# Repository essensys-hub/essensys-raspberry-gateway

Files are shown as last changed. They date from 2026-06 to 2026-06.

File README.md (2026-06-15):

# Essensys Gateway - CM5 Edition

Welcome to the hardware design repository for the **Essensys Gateway**, a high-performance home automation hub powered by the Raspberry Pi Compute Module 5 (CM5).

## Overview

The Essensys Gateway is designed as a modular, industrial-grade solution for controlling and monitoring the Essensys home automation ecosystem. It features a unique **3-board modular stack** architecture, separating core processing, high-speed storage/media, and connectivity into distinct physical layers.

**Industrial Ready**: Designed for DIN Rail mounting with a dedicated enclosure and industrial power input.

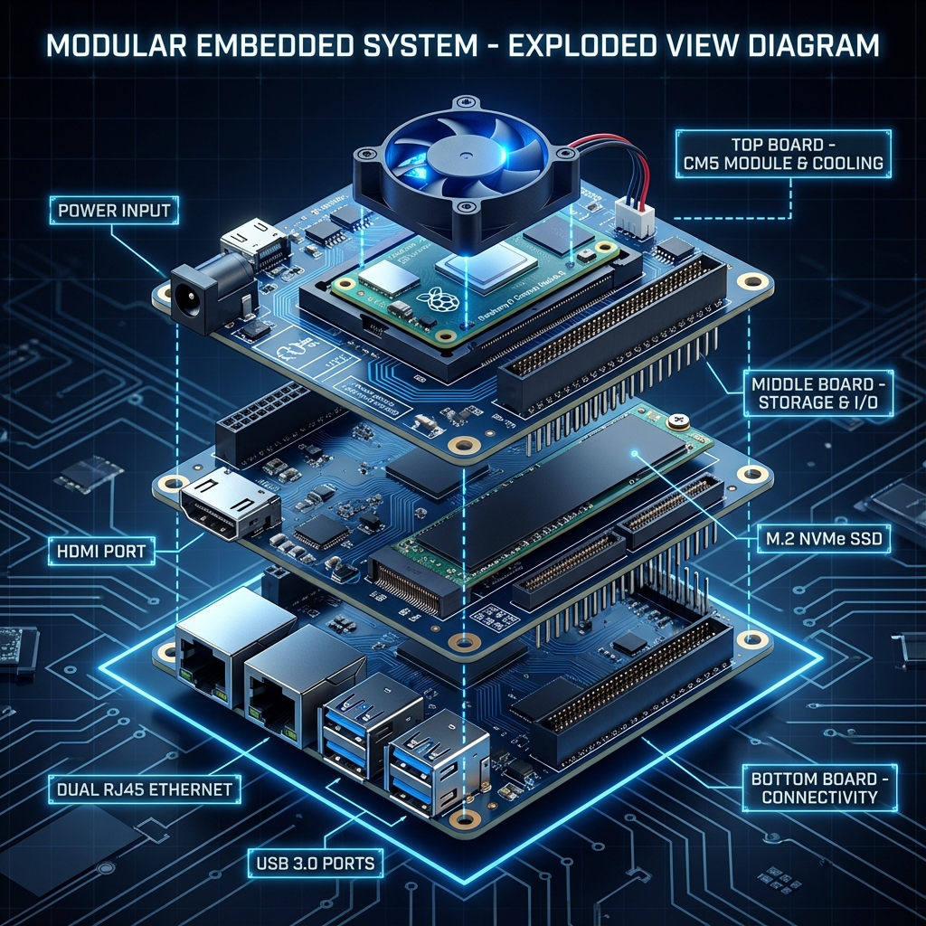
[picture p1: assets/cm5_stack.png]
Essensys CM5 Modular Stack Concept

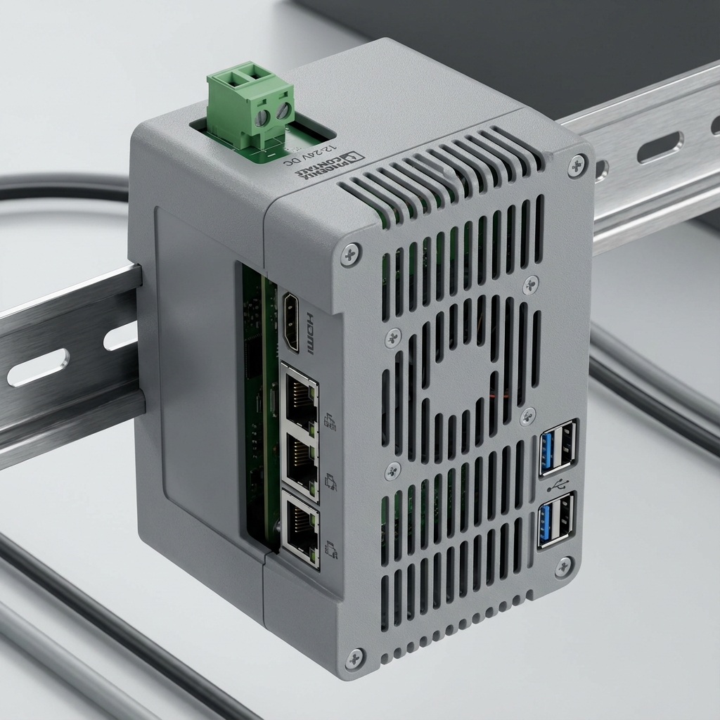
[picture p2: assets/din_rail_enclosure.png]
DIN Rail Enclosure Visualization


## Architecture

The system is built as a "sandwich" of three stacked PCBs (100mm x 100mm), interconnected by high-density Mezzanine connectors:

### 1. Top Board: Core & Processing
The brain of the operation.
- **Compute Module**: Raspberry Pi CM5 (Quad-core ARM Cortex-A76).
- **Cooling**: Dedicated active cooling fan with PWM control.
- **Power**: 2-Pin Terminal Block (Bornier) for 12V-24V DC Input.

### 2. Middle Board: Storage & Media
Dedicated layer for high-speed extensions.
- **Storage**: M.2 M-Key slot for NVMe SSDs (PCIe Gen 2 x1).
- **Video**: Full-size HDMI output for local display or debugging.

### 3. Bottom Board: Connectivity
High-density IO for network integration.
- **Ethernet**: 
  - 1x Gigabit Ethernet (Native CM5).
  - 1x Gigabit Ethernet (via USB 3.0 Bridge).
- **USB**: 3x USB 3.0 Type-A ports for peripherals (Z-Wave/Zigbee sticks, etc.).

## Specifications

| Feature | Specification |
| :--- | :--- |
| **Processor** | Raspberry Pi Compute Module 5 |
| **RAM** | Up to 8GB LPDDR4X (depending on CM5 variant) |
| **Storage** | M.2 NVMe SSD (2230/2242/2280 supported via Mid Board) |
| **Network** | Dual Gigabit Ethernet (1x Native, 1x RTL8153) |
| **USB** | 3x USB 3.0 (via VL817 Hub) |
| **Video** | 1x HDMI 2.0 (4Kp60 supported) |
| **Power** | 12V-24V DC Industrial Input (Terminal Block) |
| **Dimensions** | 100mm x 100mm x 45mm (DIN Rail Mountable) |

## Repository Structure

- `src/cm5/`: KiCad Design Files
  - `CM5_Stack_Top/`: Top board design (CM5 + Fan).
  - `CM5_Stack_Mid/`: Middle board design (M.2 + HDMI).
  - `CM5_Stack_Bot/`: Bottom board design (Dual Eth + USB Hub).
- `docs/`: **Documentation MkDocs** (miroir structure [essensys-raspberry-install](https://github.com/essensys-hub/essensys-raspberry-install), adaptée Gateway CM5)
- `nix/`: Configuration NixOS (branche `nixos`)
- `scripts/`: Tests WAN HTTPS, utilitaires déploiement

## Documentation

Site en ligne : [essensys-hub.github.io/essensys-raspberry-gateway](https://essensys-hub.github.io/essensys-raspberry-gateway/)

```bash
pip install mkdocs-material mkdocs-minify-plugin mkdocs-git-revision-date-localized-plugin
mkdocs serve   # http://127.0.0.1:8000
```

## Manufacturing & Assembly

This project is designed for manufacturing services like [PCBWay](https://www.pcbway.com/).
- **PCB Stackup**: 4-Layer controlled impedance (JLC2313 or similar).
- **Assembly**: SMT assembly required for high-density connectors and BGA/QFN components (VL817, RTL8153).
- **Connectors**: Uses high-speed board-to-board mezzanine connectors for robust signal integrity of PCIe and USB 3.0 signals between layers.

---
*Designed for the Essensys Smart Home Project.*

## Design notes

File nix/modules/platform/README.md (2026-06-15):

# CM5 / Pi5 NixOS platform notes

This module enables a **headless** Raspberry Pi CM5 profile using `pkgs.linuxPackages_rpi4`
(nixpkgs community path for Pi 5-class hardware).

## Prerequisites (manual, before first NixOS install)

1. Flash or install base firmware on CM5 eMMC.
2. Enable **PCIe / NVMe** in CM5 EEPROM or firmware config per Raspberry Pi documentation.
3. Verify `lsblk` shows `nvme0n1` before relying on `services.essensys.nvme`.
4. Note **MAC addresses** for eth0 (native) and eth1 (USB RTL8153 on Essensys IO board):
   `ip link show`

## Kernel alternatives

- **Default here**: `linuxPackages_rpi4` on nixos-24.11
- **Alternative**: pin `nixos-raspberrypi` flake input for vendor kernel (see `docs/nixos-install-cm5.md`)

## Initrd

NVMe modules are added when `services.essensys.nvme.enable = true`.

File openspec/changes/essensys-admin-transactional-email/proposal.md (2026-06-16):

## Why

Admins create users and assign gateways/armoires via the support-site admin (`UserManager`), but **no transactional email** is sent (welcome credentials, allocation summary, password reset). Operators must manually communicate access details. SMTP is configured for **newsletter only** (`internal/admin/newsletter.go`), causing support friction and user confusion when accounts are created without notification.

## What Changes

- **Transactional email engine** in `essensys-user-portal-backend`: reusable mailer built on existing `SMTP_*` / gomail, separate from newsletter drafts.
- **Email templates** stored in PostgreSQL, editable in admin UI: types `user_welcome`, `device_allocation`, `password_reset`, `role_updated` (extensible).
- **Template variables** (`{{first_name}}`, `{{email}}`, `{{portal_url}}`, `{{gateway_name}}`, `{{gateway_ip}}`, `{{armoire_label}}`, `{{temporary_password}}`, etc.).
- **Auto-send hooks**: optional send on `CreateUser`, `UpdateUserLinks` when template `auto_send=true`.
- **Resend button** per user row: « Renvoyer email » (welcome or allocation template).
- **Admin section** new tab « Modèles email » in `essensys-support-site/site/src/pages/Admin.jsx`.
- **Audit log** entries for every send / resend / failure.
- **SMTP health**: admin-visible status + test send endpoint.

## Capabilities

### New Capabilities

- `transactional-email-engine`: send, render templates, SMTP errors, audit.
- `email-templates-admin`: CRUD templates, preview, enable/disable auto-send per type.
- `user-lifecycle-notifications`: hooks on user create, link update, password reset (phase 2).
- `admin-ui-email-actions`: resend button, templates editor, test email.

### Modified Capabilities

- `admin-module-migration`: extend admin routes with `/api/admin/email-templates/*`, `/api/admin/email/health`, and `/api/admin/users/{id}/resend-email`.

## Impact

- **Modified repos**: `essensys-user-portal-backend` (primary), `essensys-support-site/site` (admin UI), docs.
- **Ansible**: no new secrets — reuse `vault_smtp_*` in `cloud-backend.env.j2`.
- **DB**: migration `006_email_templates.sql` + `email_send_log` table.
- **Non-goals (MVP)**: SMS, multi-language templates, HTML WYSIWYG builder, user-facing notification preferences.

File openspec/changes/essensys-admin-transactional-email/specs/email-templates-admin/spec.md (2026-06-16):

## ADDED Requirements

### Requirement: Admin CRUD for email templates
The backend SHALL expose routes under `/api/admin/email-templates` protected by `AdminAuth` and restricted to `admin_global` for write operations.

| Method | Path | Action |
|---|---|---|
| GET | `/api/admin/email-templates` | List all templates |
| GET | `/api/admin/email-templates/{slug}` | Get one template |
| PUT | `/api/admin/email-templates/{slug}` | Create or update template |
| POST | `/api/admin/email-templates/{slug}/preview` | Render preview with sample or provided data |
| POST | `/api/admin/email-templates/test` | Send test email to requesting admin |

#### Scenario: List templates
- **WHEN** `admin_global` requests `GET /api/admin/email-templates`
- **THEN** the response includes all slugs with subject, `enabled`, and `auto_send` flags

#### Scenario: Update template body
- **WHEN** `admin_global` sends `PUT /api/admin/email-templates/user_welcome` with new subject and body
- **THEN** the template is persisted and returned with updated `updated_at`

### Requirement: Template schema
Each template row SHALL include: `slug` (unique), `name`, `subject`, `body_html`, `body_text`, `enabled` (bool), `auto_send` (bool), `created_at`, `updated_at`.

#### Scenario: Disable template
- **WHEN** `enabled` is set to `false`
- **THEN** auto-send hooks and resend using that slug return HTTP 400 or skip with clear message

### Requirement: Default templates seeded on migration
Migration `006_email_templates.sql` SHALL seed disabled default templates for slugs: `user_welcome`, `device_allocation`, `password_reset`, `role_updated`.

#### Scenario: Fresh database migration
- **WHEN** migration runs on an empty database
- **THEN** four template rows exist with French placeholder content and `enabled=false`, `auto_send=false`

### Requirement: Documented template variables
Admin API documentation SHALL list allowed placeholders: `first_name`, `last_name`, `email`, `role`, `portal_url`, `temporary_password`, `gateway_name`, `gateway_ip`, `armoire_label`, `armoire_ip`, `support_email`.

#### Scenario: Preview with sample data
- **WHEN** admin posts to preview endpoint without custom payload
- **THEN** the response shows rendered subject and body using built-in sample values

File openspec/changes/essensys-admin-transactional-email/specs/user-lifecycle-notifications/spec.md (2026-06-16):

## ADDED Requirements

### Requirement: Optional auto-send on user creation
When `POST /api/admin/users` succeeds and template `user_welcome` has `enabled=true` and `auto_send=true`, the backend SHALL send the welcome email using the plaintext password from the request body.

#### Scenario: Welcome auto-send enabled
- **WHEN** admin creates a user and `user_welcome` has `auto_send=true`
- **THEN** the user receives a welcome email and audit logs `EMAIL_SENT` with slug `user_welcome`

#### Scenario: Welcome auto-send disabled
- **WHEN** `user_welcome.auto_send` is `false`
- **THEN** the user is created without email; admin may trigger resend later

#### Scenario: Create succeeds even if email fails
- **WHEN** user creation succeeds but SMTP send fails
- **THEN** HTTP 201 or 200 is still returned for user creation, email failure is logged, and response may include `email_sent: false`

### Requirement: Optional auto-send on device allocation
When `PUT /api/admin/users/{id}/links` updates `linked_gateway_id` or `linked_armoire_id` and template `device_allocation` has `enabled=true` and `auto_send=true`, the backend SHALL send an allocation summary email.

#### Scenario: Link gateway and armoire
- **WHEN** admin saves links for a user with gateway hostname and armoire machine resolved
- **THEN** the email includes gateway name/IP and armoire label/IP in rendered template variables

#### Scenario: Allocation template disabled
- **WHEN** `device_allocation.enabled` is `false`
- **THEN** link update completes without sending email

### Requirement: Resend email for existing user
The backend SHALL expose `POST /api/admin/users/{id}/resend-email` accepting `{ "template_slug": string, "password": string optional }`.

#### Scenario: Resend welcome with password
- **WHEN** admin resends `user_welcome` with `password` in body
- **THEN** email is sent with `{{temporary_password}}` substituted and attempt is logged

#### Scenario: Resend welcome without password
- **WHEN** admin resends `user_welcome` without password and template contains `{{temporary_password}}`
- **THEN** placeholder is replaced with a French fallback such as « contactez votre administrateur » or API returns HTTP 400 requiring password

#### Scenario: Resend allocation template
- **WHEN** admin resends `device_allocation` for a user with linked devices
- **THEN** current gateway and armoire data are resolved and included in the email

### Requirement: Password reset email deferred to phase 2
`POST /api/auth/forgot-password` is out of MVP scope; template `password_reset` SHALL be seeded but not wired until phase 2.

#### Scenario: Forgot password not implemented in MVP
- **WHEN** client calls `POST /api/auth/forgot-password` before phase 2
- **THEN** endpoint may return HTTP 501 or remain unregistered; documented in tasks phase 2

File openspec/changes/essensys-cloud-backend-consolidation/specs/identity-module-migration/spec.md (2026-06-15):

## ADDED Requirements

### Requirement: OAuth and email auth routes preserved
The consolidated backend SHALL expose the same auth routes as `essensys-support-site/backend`: register, login, logout, Google OAuth, Apple OAuth, and admin login (deprecated).

#### Scenario: Email login returns JWT
- **WHEN** a user posts valid credentials to `POST /api/auth/login`
- **THEN** the response includes a JWT and user object with the same shape as the support-site backend

#### Scenario: Google OAuth redirect unchanged
- **WHEN** a browser requests `GET /api/auth/google/login`
- **THEN** the user is redirected to Google OAuth with the same callback URL path `/api/auth/google/callback`

### Requirement: JWT emit and validate in same binary
The consolidated backend SHALL sign JWTs in the identity module and validate them in portal/admin middleware using the same `JWT_SECRET`.

#### Scenario: Portal accepts JWT from consolidated login
- **WHEN** a user logs in via consolidated backend and calls `POST /api/portal/inject` with the returned JWT
- **THEN** the request is authenticated without calling an external auth service

### Requirement: Profile routes preserved
Routes `GET/PUT/DELETE /api/profile`, `GET /api/profile/export`, `PUT /api/profile/links`, and `GET /api/devices/nearby` SHALL remain available with identical paths and authorization rules.

#### Scenario: Profile read after OAuth login
- **WHEN** an authenticated user requests `GET /api/profile`
- **THEN** the response includes email, role, and linked device fields from PostgreSQL `users`

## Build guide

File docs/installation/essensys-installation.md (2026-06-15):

# Étape 4 : Installation d'Essensys

!!! info "Gateway CM5 (ce dépôt)"
    Sur **Gateway CM5**, utilisez **Ansible** et non `install.sh` :
    ```bash
    cd essensys-ansible
    ansible-playbook install.gateway.yml -i inventory.gateway
    ```
    Voir [Gateway CM5 (dual-NIC)](gateway-cm5.md). La section ci-dessous décrit encore le parcours **Raspberry Pi 4** historique (`install.raspberrypi.yml` / `install.sh`).

Cette section explique comment installer Essensys (backend et frontend) sur le Raspberry Pi en fonction de l'utilisateur que vous avez choisi lors de l'installation de l'OS.

## Prérequis

- [ ] Raspberry Pi OS installé et démarré.
- [ ] Connexion SSH établie.
- [ ] Accès Internet fonctionnel sur le Raspberry Pi.

---

## Méthode d'installation

Choisissez la méthode correspondant à votre nom d'utilisateur configuré à l'étape précédente.

=== "Utilisateur `essensys` (Recommandé)"

    Si vous avez respecté le nom d'utilisateur `essensys`, vous pouvez utiliser la commande rapide :

    1. **Connectez-vous en SSH** :
       ```bash
       ssh essensys@<ip-du-pi>
       ```

    2. **Lancez l'installation automatique** :
       ```bash
       sudo curl -sL https://raw.githubusercontent.com/essensys-hub/essensys-raspberry-install/refs/heads/V.1.1.0/install.sh | sudo bash
       ```

       example: 
       ```
essensys@essensys-server:~ $ sudo curl -sL https://raw.githubusercontent.com/essensys-hub/essensys-raspberry-install/refs/heads/V.1.1.0/install.sh | sudo bash
[INFO] Verification des prerequis (git, ansible)...
Hit:1 http://deb.debian.org/debian trixie InRelease
Get:2 http://deb.debian.org/debian trixie-updates InRelease [47.3 kB]                                        
Hit:3 http://archive.raspberrypi.com/debian trixie InRelease                                                 
Get:4 http://deb.debian.org/debian-security trixie-security InRelease [43.4 kB]                              
Hit:5 https://deb.nodesource.com/node_20.x nodistro InRelease                         
Fetched 90.7 kB in 0s (211 kB/s)
Reading package lists... Done
[INFO] Git deja installe
[INFO] Execution via curl | bash detectee, bootstrap du depot...
[INFO] Depot essensys-raspberry-install deja present, mise a jour...
Already up to date.
----------------------------------------
DOMAIN_FILE: /home/essensys/domain.txt
----------------------------------------
[INFO] domain.txt detecte. Saisissez le domaine WAN a utiliser.
[INFO] ref: https://essensys-hub.github.io/essensys-raspberry-install/installation/wan/
Domaine WAN (ex: mon.monwan.io):  essensys.rhinosys.io 
[INFO] Domaine enregistre dans /home/essensys/domain.txt
```
Il faut mettre le nom du DNS relier à votre adresse de votre installation WAN router.

```
[WARN] resize2fs_once introuvable, etape ignoree
[INFO] Ansible deja installe
[INFO] Depot deja present, mise a jour...
remote: Enumerating objects: 56, done.
remote: Counting objects: 100% (56/56), done.
remote: Compressing objects: 100% (39/39), done.
remote: Total 51 (delta 7), reused 51 (delta 7), pack-reused 0 (from 0)
Unpacking objects: 100% (51/51), 2.68 MiB | 13.51 MiB/s, done.
From https://github.com/essensys-hub/essensys-ansible
   95a3729..7ed78a0  V.1.0.0    -> origin/V.1.0.0
 + ed7ac00...104dde6 gh-pages   -> origin/gh-pages  (forced update)
Already on 'V.1.0.0'
Your branch is behind 'origin/V.1.0.0' by 1 commit, and can be fast-forwarded.
  (use "git pull" to update your local branch)
Updating 95a3729..7ed78a0
Fast-forward
 roles/raspberry_push_status/files/push_status.py | 4 ++--
 1 file changed, 2 insertions(+), 2 deletions(-)
[INFO] Lancement du playbook d'installation Raspberry Pi...

PLAY [Installation Essensys Raspberry Pi] *****************************************************************************************************************************************

TASK [Gathering Facts] ************************************************************************************************************************************************************
[WARNING]: Host 'localhost' is using the discovered Python interpreter at '/usr/bin/python3.13', but future installation of another Python interpreter could cause a different interpreter to be discovered. See https://docs.ansible.com/ansible-core/2.19/reference_appendices/interpreter_discovery.html for more information.
ok: [localhost]

TASK [raspberry_common : Mettre a jour le cache APT] ******************************************************************************************************************************
ok: [localhost]

TASK [raspberry_common : Installer les dependances systeme] ***********************************************************************************************************************
ok: [localhost]

TASK [raspberry_common : Definir les variables d'architecture] ********************************************************************************************************************
ok: [localhost]

TASK [raspberry_common : Verifier la presence de Go] ******************************************************************************************************************************
ok: [localhost]

TASK [raspberry_common : Telecharger Go] ******************************************************************************************************************************************
skipping: [localhost]

TASK [raspberry_common : Installer Go] ********************************************************************************************************************************************
skipping: [localhost]

TASK [raspberry_common : Ajouter Go au PATH systeme] ******************************************************************************************************************************
ok: [localhost]

TASK [raspberry_common : Telecharger le script Node.js] ***************************************************************************************************************************
ok: [localhost]

TASK [raspberry_common : Executer le script Node.js] ******************************************************************************************************************************
ok: [localhost]

TASK [raspberry_common : Installer Node.js] ***************************************************************************************************************************************
ok: [localhost]

TASK [raspberry_common : Creer l'utilisateur de service] **************************************************************************************************************************
ok: [localhost]

TASK [raspberry_common : Creer les repertoires d'installation] ********************************************************************************************************************
ok: [localhost] => (item=/opt/essensys)
changed: [localhost] => (item=/opt/essensys/backend)
changed: [localhost] => (item=/opt/essensys/frontend)
ok: [localhost] => (item=/opt/essensys/logs)

TASK [raspberry_common : Creer le repertoire de logs backend] *********************************************************************************************************************
ok: [localhost] => (item=/var/logs/Essensys)
ok: [localhost] => (item=/var/logs/Essensys/backend)

TASK [raspberry_common : S'assurer que Redis est actif] ***************************************************************************************************************************
ok: [localhost]

TASK [raspberry_backend : Definir variables backend] ******************************************************************************************************************************
ok: [localhost]

TASK [raspberry_backend : Cloner ou mettre a jour le backend] *********************************************************************************************************************
changed: [localhost]

TASK [raspberry_backend : Arreter le service backend avant mise a jour] ***********************************************************************************************************
ok: [localhost]

TASK [raspberry_backend : Copier le backend vers le repertoire d'installation] ****************************************************************************************************
changed: [localhost]

TASK [raspberry_backend : Synchroniser les dependances Go] ************************************************************************************************************************
changed: [localhost]

TASK [raspberry_backend : Telecharger les dependances Go si necessaire] ***********************************************************************************************************
skipping: [localhost]

TASK [raspberry_backend : Reexecuter go mod tidy apres download] ******************************************************************************************************************
skipping: [localhost]

TASK [raspberry_backend : Compiler le backend] ************************************************************************************************************************************
changed: [localhost]

TASK [raspberry_backend : Creer le fichier config.yaml si absent] *****************************************************************************************************************
ok: [localhost]

TASK [raspberry_backend : Forcer le port 7070 dans config.yaml] *******************************************************************************************************************
changed: [localhost]

TASK [raspberry_backend : Installer le service systemd du backend] ****************************************************************************************************************
ok: [localhost]

TASK [raspberry_backend : Recharger systemd] **************************************************************************************************************************************
ok: [localhost]

TASK [raspberry_backend : Definir les permissions du backend] *********************************************************************************************************************
changed: [localhost]

TASK [raspberry_backend : Demarrer le service backend] ****************************************************************************************************************************
changed: [localhost]

TASK [raspberry_backend : S'assurer que Redis est actif] **************************************************************************************************************************
ok: [localhost]

TASK [raspberry_frontend : Definir variables frontend] ****************************************************************************************************************************
ok: [localhost]

TASK [raspberry_frontend : Cloner ou mettre a jour le frontend] *******************************************************************************************************************
ok: [localhost]

TASK [raspberry_frontend : Copier le frontend vers le repertoire d'installation] **************************************************************************************************
changed: [localhost]

TASK [raspberry_frontend : Installer les dependances npm] *************************************************************************************************************************
changed: [localhost]

TASK [raspberry_frontend : Builder le frontend] ***********************************************************************************************************************************
changed: [localhost]

TASK [raspberry_frontend : Verifier la presence du build] *************************************************************************************************************************
ok: [localhost]

TASK [raspberry_frontend : Echouer si le build est absent] ************************************************************************************************************************
skipping: [localhost]

TASK [raspberry_frontend : Definir les permissions du frontend] *******************************************************************************************************************
ok: [localhost]

TASK [raspberry_nginx : Copier le format de log nginx] ****************************************************************************************************************************
ok: [localhost]

TASK [raspberry_nginx : Deployer la configuration nginx principale] ***************************************************************************************************************
ok: [localhost]

TASK [raspberry_nginx : Activer le site nginx] ************************************************************************************************************************************
ok: [localhost]

TASK [raspberry_nginx : Desactiver la configuration nginx par defaut] *************************************************************************************************************
ok: [localhost]

TASK [raspberry_nginx : Deployer la configuration nginx frontend interne] *********************************************************************************************************
ok: [localhost]

TASK [raspberry_nginx : Activer le site nginx frontend interne] *******************************************************************************************************************
ok: [localhost]

TASK [raspberry_nginx : Creer les fichiers de logs nginx] *************************************************************************************************************************
changed: [localhost] => (item=/var/log/nginx/essensys-api-detailed.log)
changed: [localhost] => (item=/var/log/nginx/essensys-api-trace.log)
changed: [localhost] => (item=/var/log/nginx/essensys-api-error.log)
changed: [localhost] => (item=/var/log/nginx/essensys-access.log)
changed: [localhost] => (item=/var/log/nginx/essensys-error.log)
changed: [localhost] => (item=/var/log/nginx/frontend-internal-error.log)

TASK [raspberry_nginx : Tester la configuration nginx] ****************************************************************************************************************************
ok: [localhost]

TASK [raspberry_nginx : Recharger nginx] ******************************************************************************************************************************************
changed: [localhost]

TASK [raspberry_traefik : Definir les variables Traefik] **************************************************************************************************************************
ok: [localhost]

TASK [raspberry_traefik : Verifier le binaire Traefik] ****************************************************************************************************************************
ok: [localhost]

TASK [raspberry_traefik : Lire le domaine WAN] ************************************************************************************************************************************
ok: [localhost]

TASK [raspberry_traefik : Calculer le domaine WAN] ********************************************************************************************************************************
ok: [localhost]

TASK [raspberry_traefik : Telecharger Traefik] ************************************************************************************************************************************
skipping: [localhost]

TASK [raspberry_traefik : Extraire Traefik] ***************************************************************************************************************************************
skipping: [localhost]

TASK [raspberry_traefik : Installer le binaire Traefik] ***************************************************************************************************************************
skipping: [localhost]

TASK [raspberry_traefik : Creer les repertoires Traefik] **************************************************************************************************************************
ok: [localhost] => (item=/etc/traefik)
ok: [localhost] => (item=/etc/traefik/dynamic)
ok: [localhost] => (item=/var/log/traefik)
ok: [localhost] => (item=/var/lib/traefik)

TASK [raspberry_traefik : Deployer la configuration Traefik] **********************************************************************************************************************
ok: [localhost]

TASK [raspberry_traefik : Deployer la configuration dynamique locale] *************************************************************************************************************
ok: [localhost]

TASK [raspberry_traefik : Deployer la configuration dynamique WAN] ****************************************************************************************************************
ok: [localhost]

TASK [raspberry_traefik : Creer acme.json] ****************************************************************************************************************************************
changed: [localhost]

TASK [raspberry_traefik : Creer users.htpasswd] ***********************************************************************************************************************************
changed: [localhost]

TASK [raspberry_traefik : Installer le service de blocage Traefik] ****************************************************************************************************************
ok: [localhost]

TASK [raspberry_traefik : Installer generate-htpasswd.sh] *************************************************************************************************************************
ok: [localhost]

TASK [raspberry_traefik : Installer le service systemd Traefik block] *************************************************************************************************************
ok: [localhost]

TASK [raspberry_traefik : Installer le service systemd Traefik] *******************************************************************************************************************
ok: [localhost]

TASK [raspberry_traefik : Recharger systemd] **************************************************************************************************************************************
ok: [localhost]

TASK [raspberry_traefik : Activer et demarrer Traefik] ****************************************************************************************************************************
changed: [localhost]

TASK [raspberry_traefik : Activer et demarrer le service de blocage] **************************************************************************************************************
changed: [localhost]

TASK [raspberry_adguard : Definir l'architecture AdGuard] *************************************************************************************************************************
ok: [localhost]

TASK [raspberry_adguard : Verifier resolved.conf] *********************************************************************************************************************************
ok: [localhost]

TASK [raspberry_adguard : Desactiver DNSStubListener pour systemd-resolved] *******************************************************************************************************
skipping: [localhost]

TASK [raspberry_adguard : Verifier resolv.conf source] ****************************************************************************************************************************
ok: [localhost]

TASK [raspberry_adguard : Verifier resolv.conf] ***********************************************************************************************************************************
skipping: [localhost]

TASK [raspberry_adguard : Installer AdGuard Home] *********************************************************************************************************************************
skipping: [localhost]

TASK [raspberry_adguard : Deployer la configuration AdGuard Home] *****************************************************************************************************************
ok: [localhost]

TASK [raspberry_adguard : Installer le service AdGuard Home] **********************************************************************************************************************
ok: [localhost]

TASK [raspberry_adguard : Demarrer AdGuard Home] **********************************************************************************************************************************
changed: [localhost]

TASK [raspberry_adguard : Attendre l'API AdGuard] *********************************************************************************************************************************
ok: [localhost]

TASK [raspberry_adguard : Configurer le rewrite DNS pour mon.essensys.fr] *********************************************************************************************************
ok: [localhost]

TASK [raspberry_monitor : Copier le script de monitoring] *************************************************************************************************************************
ok: [localhost]

TASK [raspberry_monitor : Copier le setup du monitoring] **************************************************************************************************************************
ok: [localhost]

TASK [raspberry_monitor : Executer le setup du monitoring] ************************************************************************************************************************
changed: [localhost]

TASK [raspberry_logrotate : Installer la configuration logrotate] *****************************************************************************************************************
ok: [localhost]

TASK [raspberry_push_status : Copier le script de push status] ********************************************************************************************************************
changed: [localhost]

TASK [raspberry_push_status : Installer le service systemd de push status] ********************************************************************************************************
ok: [localhost]

TASK [raspberry_push_status : Installer le timer systemd de push status] **********************************************************************************************************
ok: [localhost]

TASK [raspberry_push_status : Recharger systemd] **********************************************************************************************************************************
ok: [localhost]

TASK [raspberry_push_status : Activer le timer push status] ***********************************************************************************************************************
ok: [localhost]

PLAY RECAP ************************************************************************************************************************************************************************
localhost                  : ok=76   changed=20   unreachable=0    failed=0    skipped=11   rescued=0    ignored=0   
[INFO] Configuration du mot de passe WAN (admin)...
Mot de passe: 
Note : saisissez le mot de passe utilise pour la connexion WAN.
[INFO] Generation du fichier htpasswd...
[WARN] Le fichier existe deja. Ajout de l'utilisateur...
[INFO] Fichier htpasswd cree avec succes: /etc/traefik/users.htpasswd
[INFO] Utilisateur: admin
[INFO] 
[INFO] Pour ajouter d'autres utilisateurs, executez a nouveau ce script
[INFO] Termine. Installation lancee via Ansible.
essensys@essensys-server:~ $ 

=== "Autre utilisateur (Personnalisé)"

    Si vous utilisez un nom d'utilisateur différent (ex: `pi`, `admin`), vous devez cloner le projet manuellement :

    1. **Connectez-vous en SSH** :
       ```bash
       ssh <votre-user>@<ip-du-pi>
       ```

    2. **Clonez le dépôt** :
       ```bash
       git clone https://github.com/essensys-hub/essensys-raspberry-install
       cd essensys-raspberry-install
       ```

    3. **Lancez l'installation avec votre utilisateur** :
       ```bash
       chmod +x install.sh
       sudo ./install.sh --user <votre-user>
       ```

---

## Options du script (Optionnel)

Le script `install.sh` accepte des arguments pour des configurations spécifiques :

| Option | Description |
| :--- | :--- |
| `--staging` | Active l'environnement de test (staging) pour Let's Encrypt. |
| `--user <username>` | Définit l'utilisateur cible (obligatoire si différent de `essensys`). |

## Architecture installée

```mermaid
graph TB
    Client[Client Essensys]
    Nginx[Nginx<br/>Port 80]
    Backend[Backend Go<br/>Port 7070]
    Frontend[Frontend React]
    
    Client -->|API/Web| Nginx
    Nginx -->|/api/*| Backend
    Nginx -->|/| Frontend
    
    style Nginx fill:#e8f5e9
    style Backend fill:#f3e5f5
```

---

!!! warning "L'adresse IP `192.168.1.151` utilisée dans cet exemple est fictive"
    Vous devez impérativement identifier l'adresse IP réelle de votre "essensys client" sur votre réseau local pour configurer les redirections de port correctement.

!!! success "Installation Terminée !"
    Félicitations ! Votre serveur Essensys est maintenant opérationnel.
    
    [:material-lan: **Configurer le réseau**](../connexion/configuration-reseau.md){ .md-button .md-button--primary }

## Dépannage

### Vérifier les services
```bash
sudo systemctl status essensys-backend
sudo systemctl status essensys-frontend
sudo systemctl status nginx
```

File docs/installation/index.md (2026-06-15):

# Introduction — Installation Gateway CM5

Cette section décrit le parcours d'installation de la **Gateway Essensys** (Compute Module 5, double RJ45).

[:material-play-circle: **Guide complet dual-NIC**](gateway-cm5.md){ .md-button .md-button--primary }

## Parcours recommandé

| Étape | Page | Description |
|---|---|---|
| 1 | [Préparation CM5](preparation-cm5.md) | Matériel, NVMe, firmware PCIe |
| 2 | [OS Debian](os-installation.md) ou [NixOS](nixos-cm5.md) | Système sur eMMC |
| 3 | [Domaine WAN](wan.md) | DuckDNS / NAT (optionnel) |
| 4 | [Déploiement Ansible](essensys-installation.md) | `install.gateway.yml` |
| 5 | [Accès](acces/index.md) | Local, WAN, [portail remote](../acces/portal-remote.md) |

## Deux systèmes d'exploitation

| OS | Playbook / outil | Quand |
|----|---|---|
| **Debian 13 + Docker** | `ansible-playbook install.gateway.yml` | Production actuelle |
| **NixOS** | `prepare.nixos-cm5.yml` puis `nixos-rebuild switch` | Variante déclarative (branche `nixos`) |

Les deux profils partagent le même modèle réseau : **eth0** = LAN/Internet, **eth1** = armoire `10.0.1.0/24`.

```bash
cd essensys-ansible
ansible-playbook install.gateway.yml -i inventory.gateway
```

## Inventaire

Variables clés dans `inventory.gateway` : `gateway_eth0_mac`, `gateway_eth1_mac`, `gateway_eth1_ip`, `gateway_armoire_hostname` (`mon.essensys.fr`), NVMe, cloud hub URL.

Voir [Gateway CM5 — section 6](gateway-cm5.md#6-deploiement) pour le détail.

## Raspberry Pi 4 (mono-interface)

Pour l'installation historique sur **Raspberry Pi 4** (un seul réseau), consultez
[essensys-raspberry-install](https://github.com/essensys-hub/essensys-raspberry-install/docs/installation/).

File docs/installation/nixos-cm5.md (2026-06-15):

# Préparation et installation NixOS — Gateway CM5

Guide pour la branche **`nixos`** de `essensys-raspberry-gateway` : profil **dual-NIC** déclaratif (eth0 LAN/HTTPS, eth1 armoire/DHCP/HTTP legacy).

!!! info "Deux OS pour la même Gateway"
    **Production actuelle** : Debian 13 + Docker via [Gateway CM5 (dual-NIC)](gateway-cm5.md).
    **NixOS** : même réseau et même NVMe, configuration via flake Nix.

---

## Partie A — Préparation Ansible

| Playbook | Rôle | Usage |
|---|---|---|
| `uninstall.cm5.yml` | `raspberry_cm5_uninstall` | Retire stack Debian/Ansible/Docker |
| `prepare.nixos-cm5.yml` | `raspberry_cm5_nixos` | Clone flake, installe Nix, prépare eMMC/NVMe |

```bash
cd essensys-ansible

ansible-playbook uninstall.cm5.yml -i inventory.gateway \
  -e confirm_cm5_uninstall=true

ansible-playbook prepare.nixos-cm5.yml -i inventory.gateway \
  -e confirm_cm5_nixos_prep=true
```

Après `prepare` :

- Flake : `/opt/essensys-nixos`
- Hardware généré : `nix/hosts/gateway-cm5/hardware-cm5.generated.nix`
- Script eMMC : `/usr/local/sbin/essensys-prepare-nixos-mmc.sh`

!!! warning "Repartition eMMC"
    Ne pas repartitionner l'eMMC depuis le système qui boot dessus. Utiliser un media recovery, puis `nixos-install --flake /opt/essensys-nixos#gateway-cm5`.

---

## Partie B — Installation NixOS (flake)

### Prérequis poste de build

- [Nix](https://nixos.org/download.html) avec flakes (`experimental-features = nix-command flakes`)
- Dépôt cloné, branche `nixos`
- `essensys-nginx` en sibling ou via flake input

### Configuration hôte

Éditer `nix/hosts/gateway-cm5/default.nix` :

| Option | Description |
|---|---|
| `gateway.eth0Mac` / `eth1Mac` | MAC réelles |
| `gateway.eth1Address` | IP statique armoire (ex. `10.0.1.1`) |
| `gateway.eth0Address` | IP LAN fixe si `bindStrict` ; `null` = DHCP |
| `nvme.device` | `/dev/disk/by-label/essensys-data` |

### Installation

```bash
# Sur la CM5
nixos-install --flake .#gateway-cm5 --no-root-password
reboot
```

Déploiement à distance :

```bash
nixos-rebuild switch --flake .#gateway-cm5 --target-host root@<eth0-ip>
```

### Secrets

Ne pas committer de secrets en clair. Utiliser **agenix** ou **sops-nix** (email ACME, tokens API, etc.).

---

## Checklist validation

```bash
ip -br addr show
ss -tlnp | grep -E ':80|:443|:53'
curl -k https://mon.essensys.local/
dig @10.0.1.1 mon.essensys.fr +short
findmnt /mnt/nvme
```

---

## Parité Ansible ↔ NixOS

| Capacité | Ansible | NixOS |
|---|---|---|
| Dual NIC | `raspberry_gateway_network` | `gateway/dual-nic.nix` |
| DHCP eth1 | `raspberry_gateway_dhcp` | `gateway/dnsmasq-armoire.nix` |
| NVMe | `raspberry_gateway_nvme` | `gateway/nvme-layout.nix` |
| Nginx armoire | `raspberry_nginx` | `essensys/nginx.nix` |
| Traefik 443 | `raspberry_traefik` | `essensys/traefik.nix` |
| Déploiement | `install.gateway.yml` | `nixos-rebuild switch` |

---

## Dépannage

| Symptôme | Action |
|---|---|
| NVMe absent | Firmware PCIe ; ou mode dégradé sans NVMe |
| eth1 absent | Module USB RTL8153 |
| Conflit port 53 | dnsmasq sur eth1 uniquement ; AdGuard sur eth0 |
| API BP_MQX_ETH | `proxy_buffering on`, `gzip off` sur Nginx eth1 |

---

## Voir aussi

- `essensys-ansible/roles/raspberry_cm5_nixos/README.md`
- OpenSpec `essensys-gateway-nixos` dans ce dépôt

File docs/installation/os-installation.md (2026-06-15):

# Installation de l'OS sur le SSD

!!! info "Gateway CM5"
    Sur CM5, l'OS est installé sur **eMMC** (Debian via imager Raspberry Pi ou NixOS via flake).
    Voir [Préparation CM5](preparation-cm5.md) et [NixOS](nixos-cm5.md). Cette page décrit surtout le parcours **Raspberry Pi 4 + SSD USB**.

Cette section explique comment installer Raspberry Pi OS sur le SSD connecté via l'adaptateur USB-SATA.

## Prérequis

- Matériel préparé (voir [Préparation du matériel](preparation.md))
- Raspberry Pi Imager installé
- SSD connecté à l'ordinateur via l'adaptateur USB-SATA

## Étapes d'installation

### Étape 1 : Lancer Raspberry Pi Imager

- [ ] Lancer **Raspberry Pi Imager** sur votre ordinateur.
#### Étape 1.1 : Sélection de board (Raspberry Pi 4)
- [ ] Cliquer sur **"DEVICE"** et sélectionner **"Raspberry Pi 4"**.
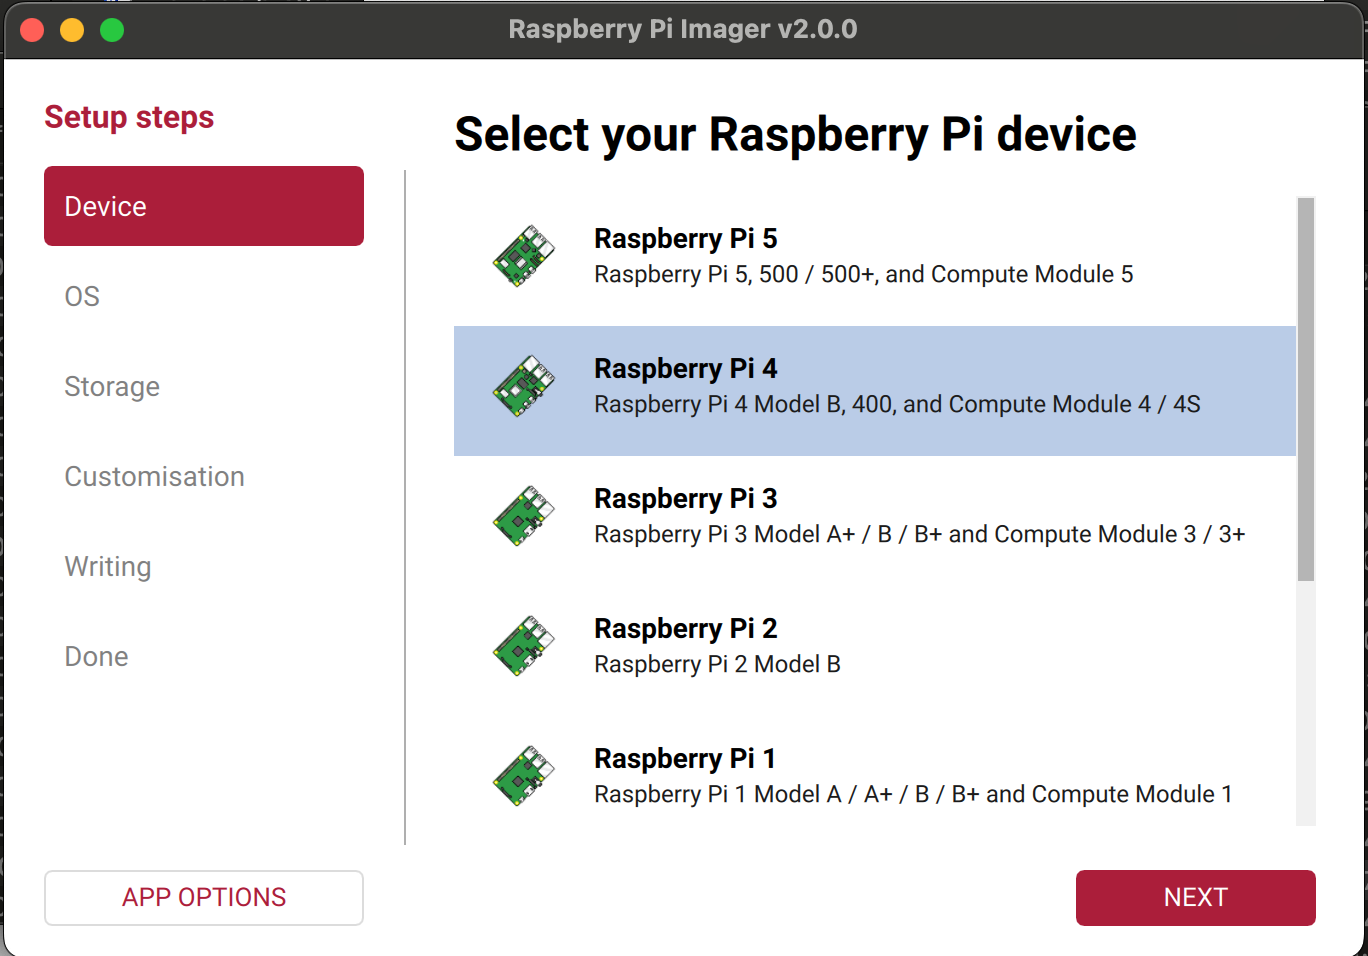
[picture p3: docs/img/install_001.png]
Étape 1.1
-  
#### Étape 1.2 :  Sélection de l'OS (Raspberry Pi OS (OTHER))
- [ ] Cliquer sur **"OS"** et sélectionner **"Raspberry Pi OS (OTHER)"**.
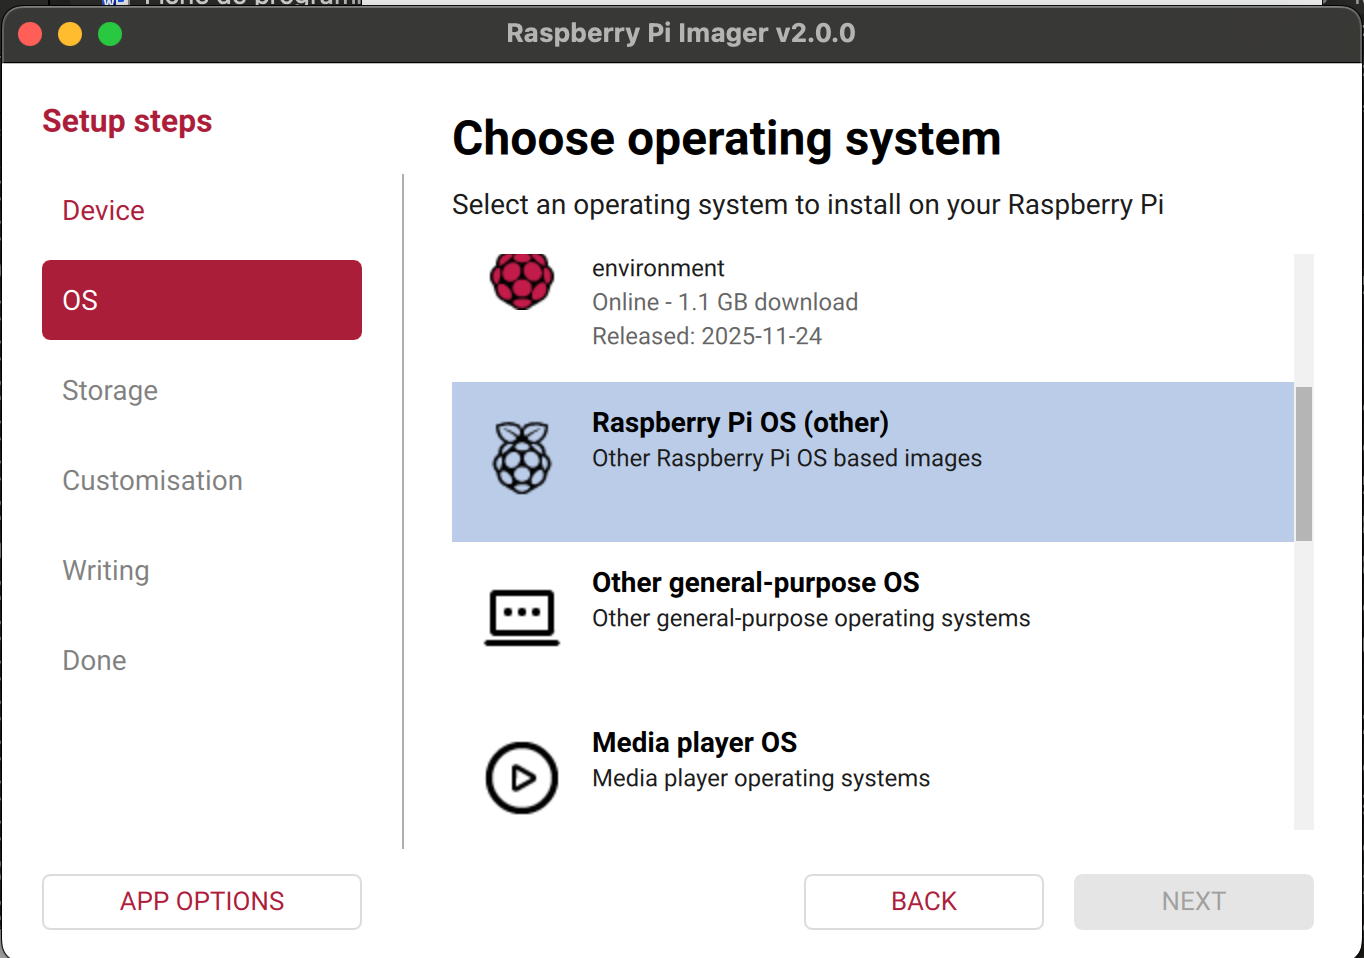
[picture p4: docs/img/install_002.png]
Étape 1.2.1
- 
- [ ] Cliquer sur **"OS"** et sélectionner **"Raspberry Pi OS Lite (64-bit)"**.
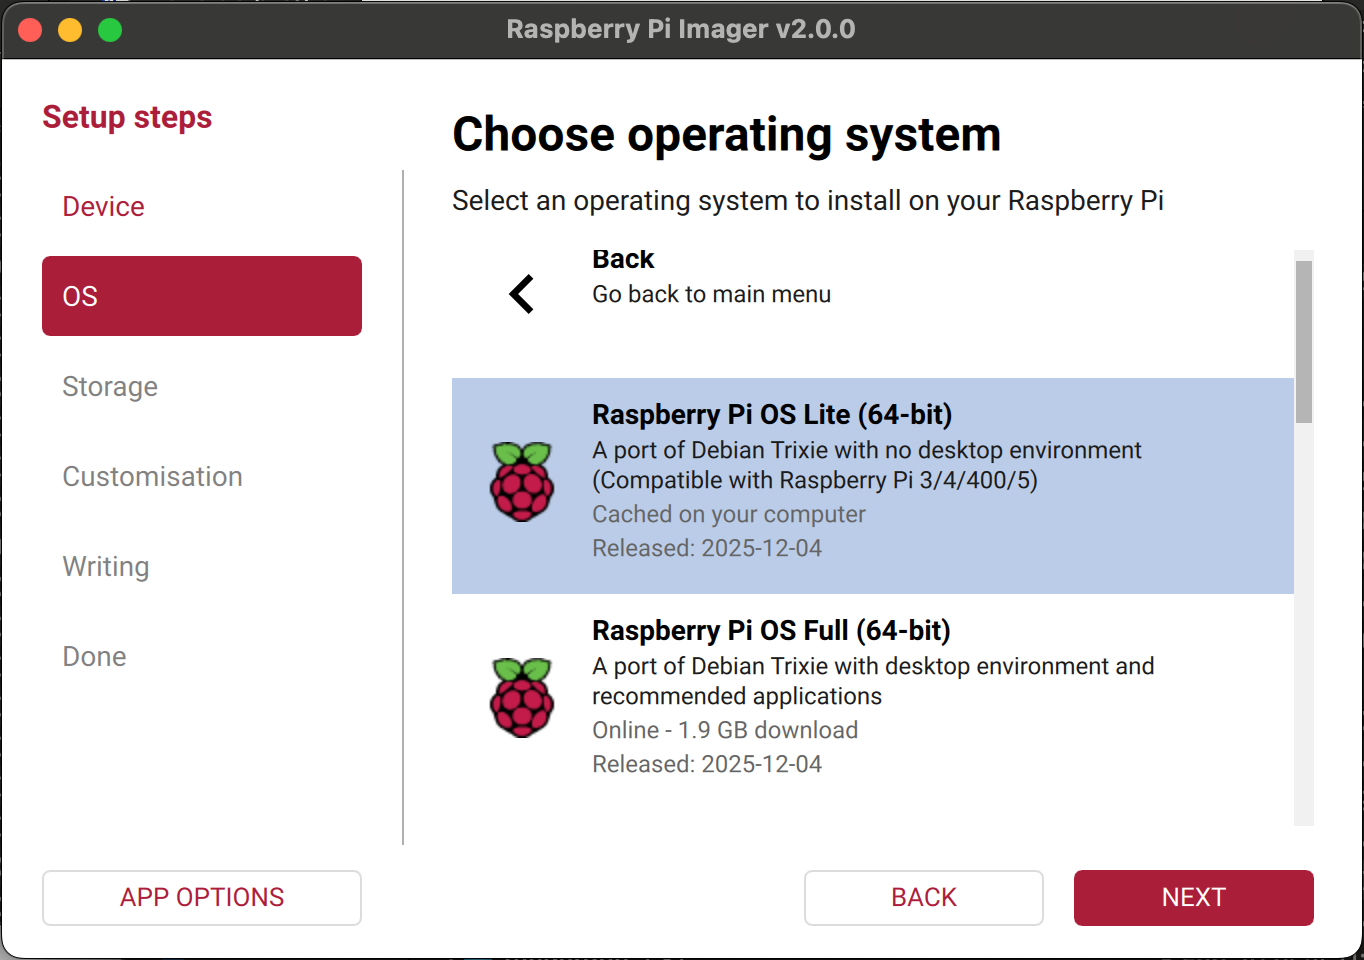
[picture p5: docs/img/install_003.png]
Étape 1.2.2
- 
#### Étape 1.3 : Configuration Storage (SSD)
- [ ] Cliquer sur **"STORAGE"** et sélectionner **"SSD"**.
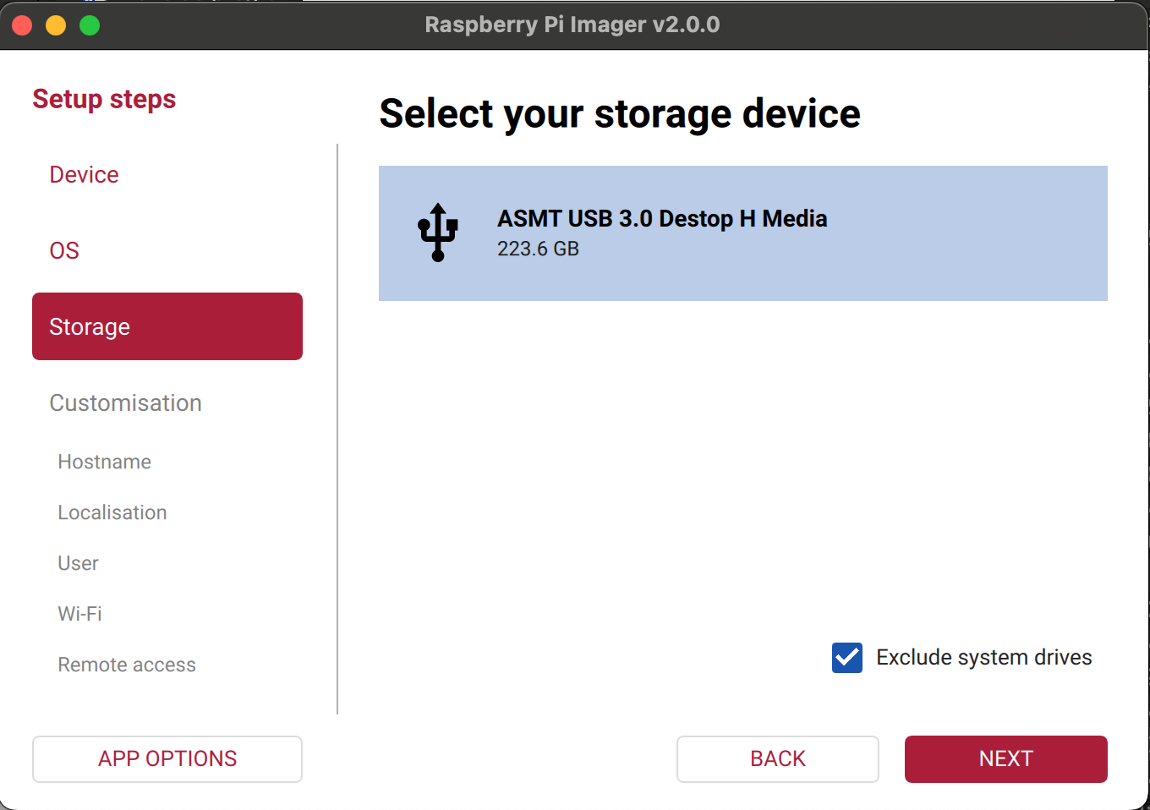
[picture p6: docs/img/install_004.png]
Étape 1.3.1
- 
#### Étape 1.4 : Configuration hostname
- [ ] Cliquer sur **"Customisation: Choose Hostname"** et sélectionner **"essensys-server"**.
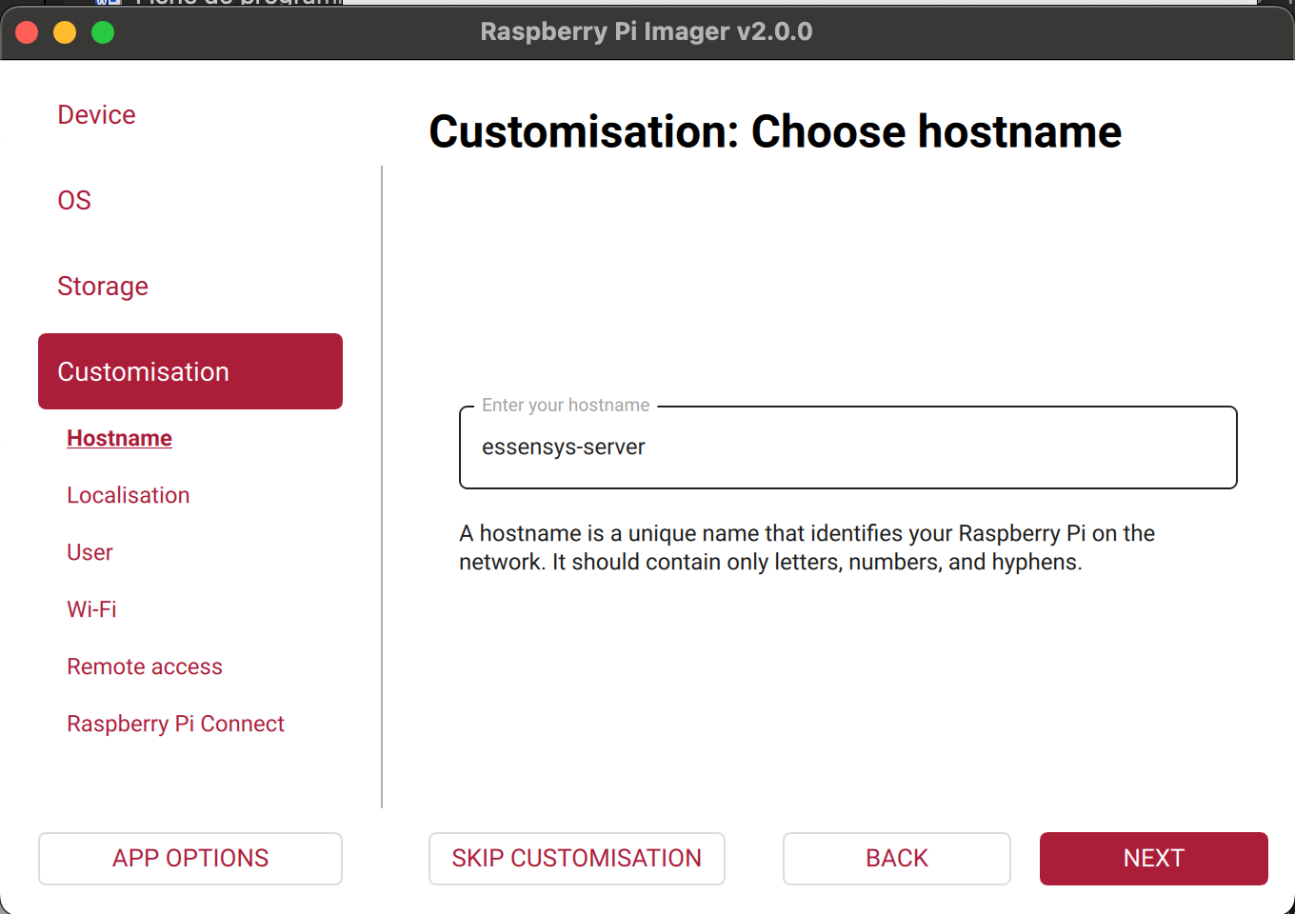
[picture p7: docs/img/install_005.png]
Étape 1.4.1
- 
#### Étape 1.5 : Configuration localisation
- [ ] Cliquer sur **"Customisation: Localization"** et sélectionner **"Europe/Paris"**.
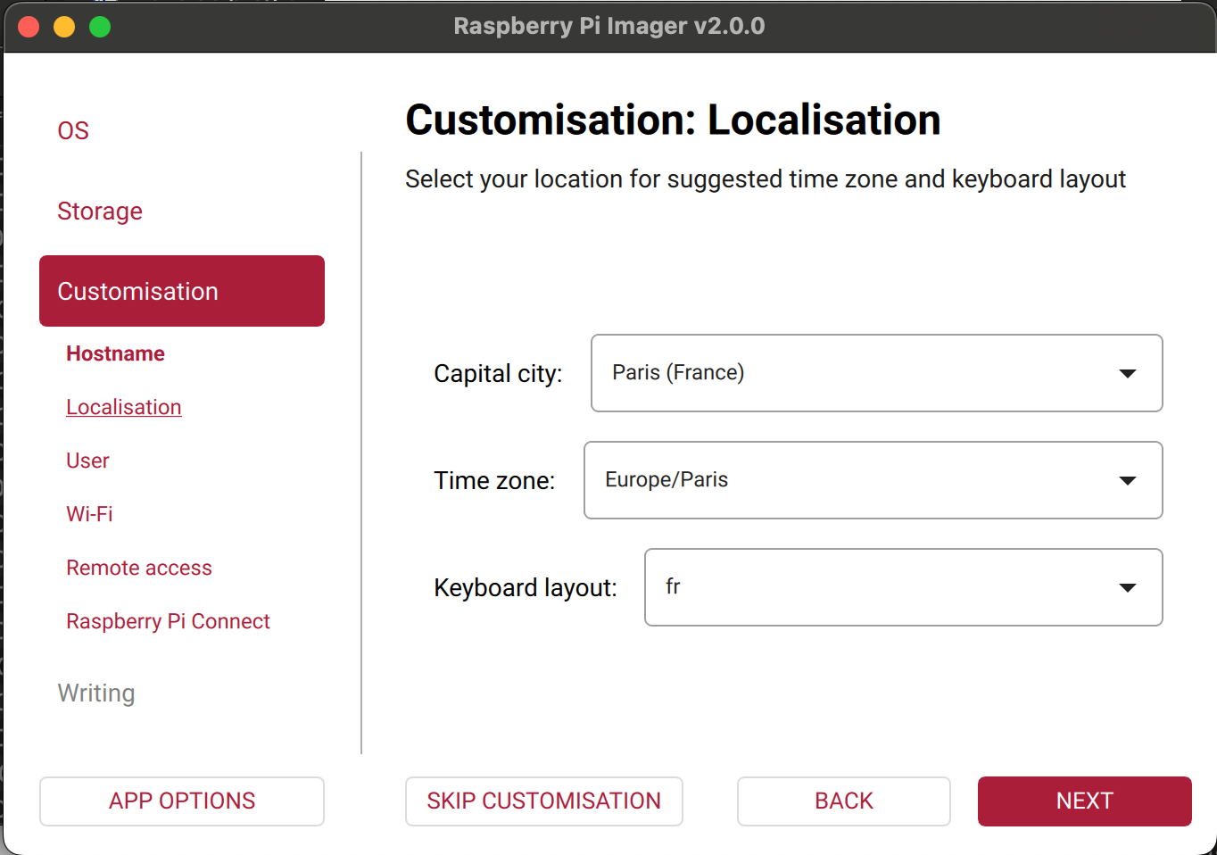
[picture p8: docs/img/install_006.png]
Étape 1.5.1
- 
#### Étape 1.6 : Configuration création utilisateur
- [ ] Cliquer sur **"Customisation: Choose Username "** et modifier le nom d'utilisateur par **"essensys"**.
- [ ] Cliquer sur **"Customisation: Choose Password "** et modifier le mot de passe par **"essensys"**.
!!! warning "Important : Choix de l'utilisateur"
    Par défaut, l'installation d'Essensys utilise l'utilisateur `essensys`. 
    **Si vous choisissez un autre nom d'utilisateur** (par exemple `pi` ou un nom personnalisé), **vous DEVEZ Ampérativement l'indiquer** lors de l'exécution du script d'installation via l'option `--user`.
    Exemple : `./install.sh --user <votre_user>`

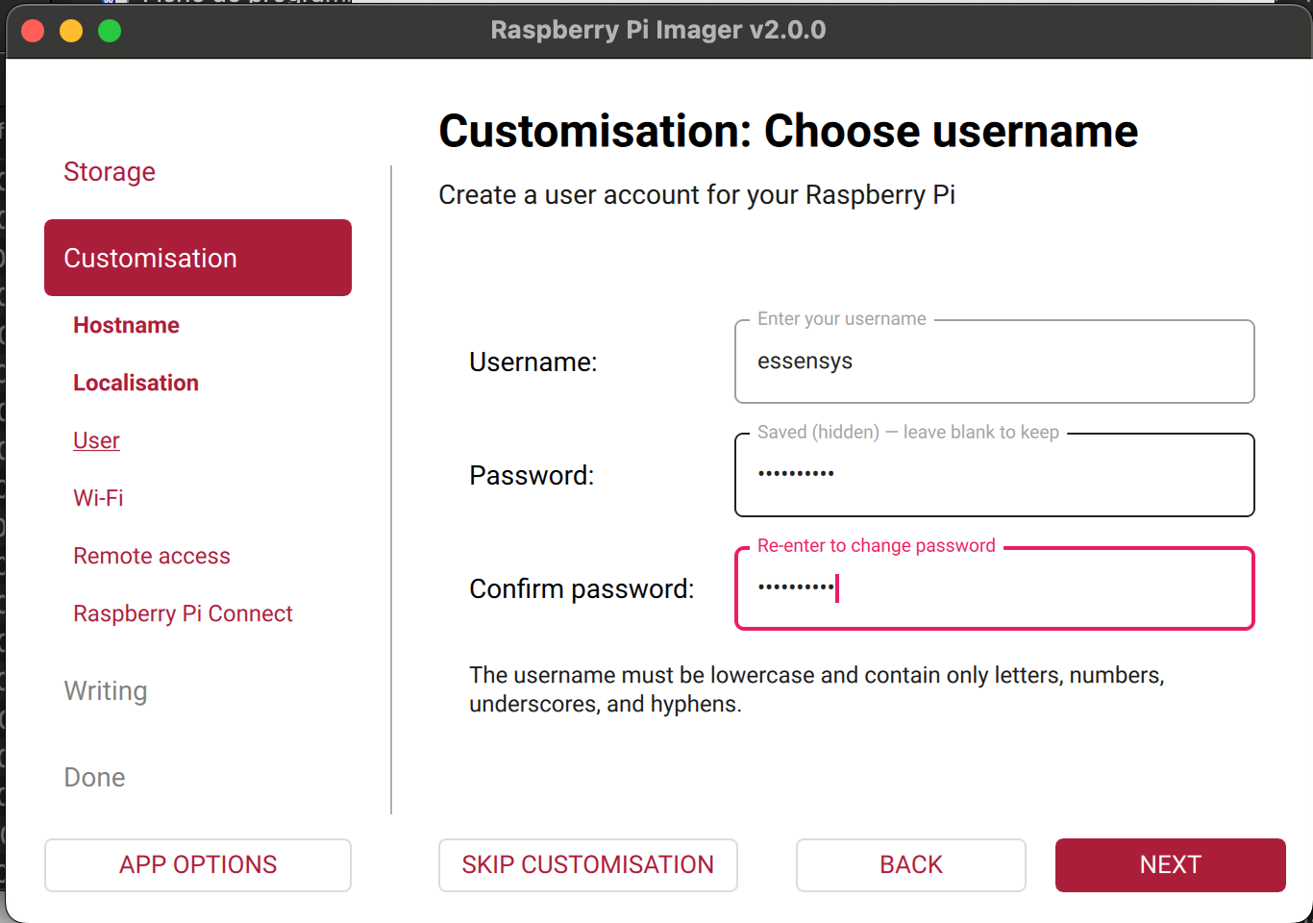
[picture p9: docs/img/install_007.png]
Étape 1.6.1
- 

#### Étape 1.7 : Configuration Wi-Fi
- [ ] Cliquer sur **"Customisation: Wi-Fi"** et modifier le SSID.
- [ ] Cliquer sur **"Customisation: Wi-Fi"** et modifier le mot de passe.
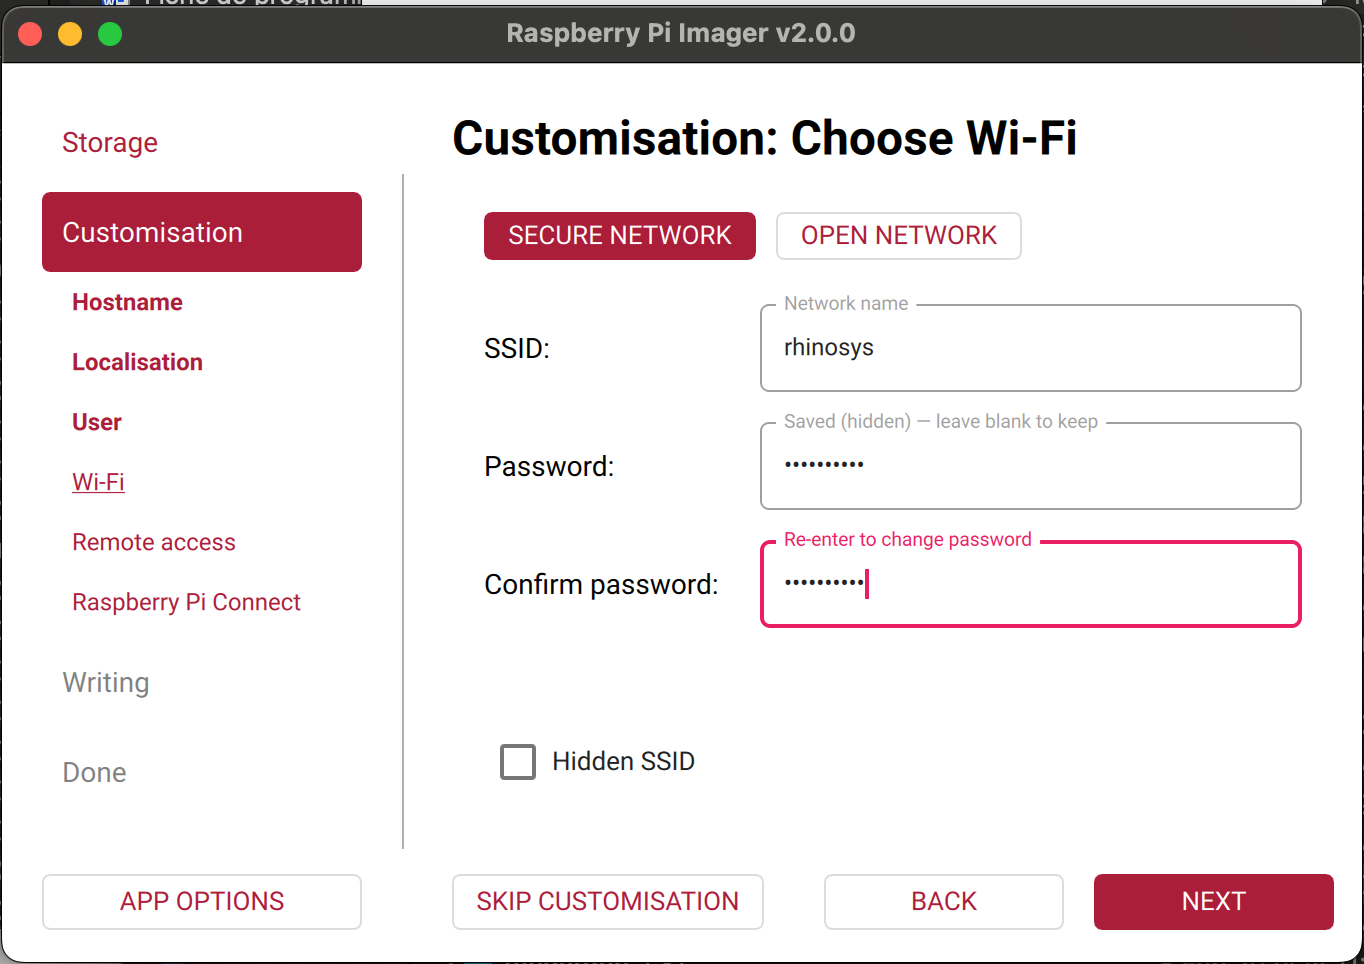
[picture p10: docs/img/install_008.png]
Étape 1.7.1
- 
#### Étape 1.8 : Options SSH
- [ ] Cliquer sur **"Customisation: SSH"** et cocher "Enable SSH".
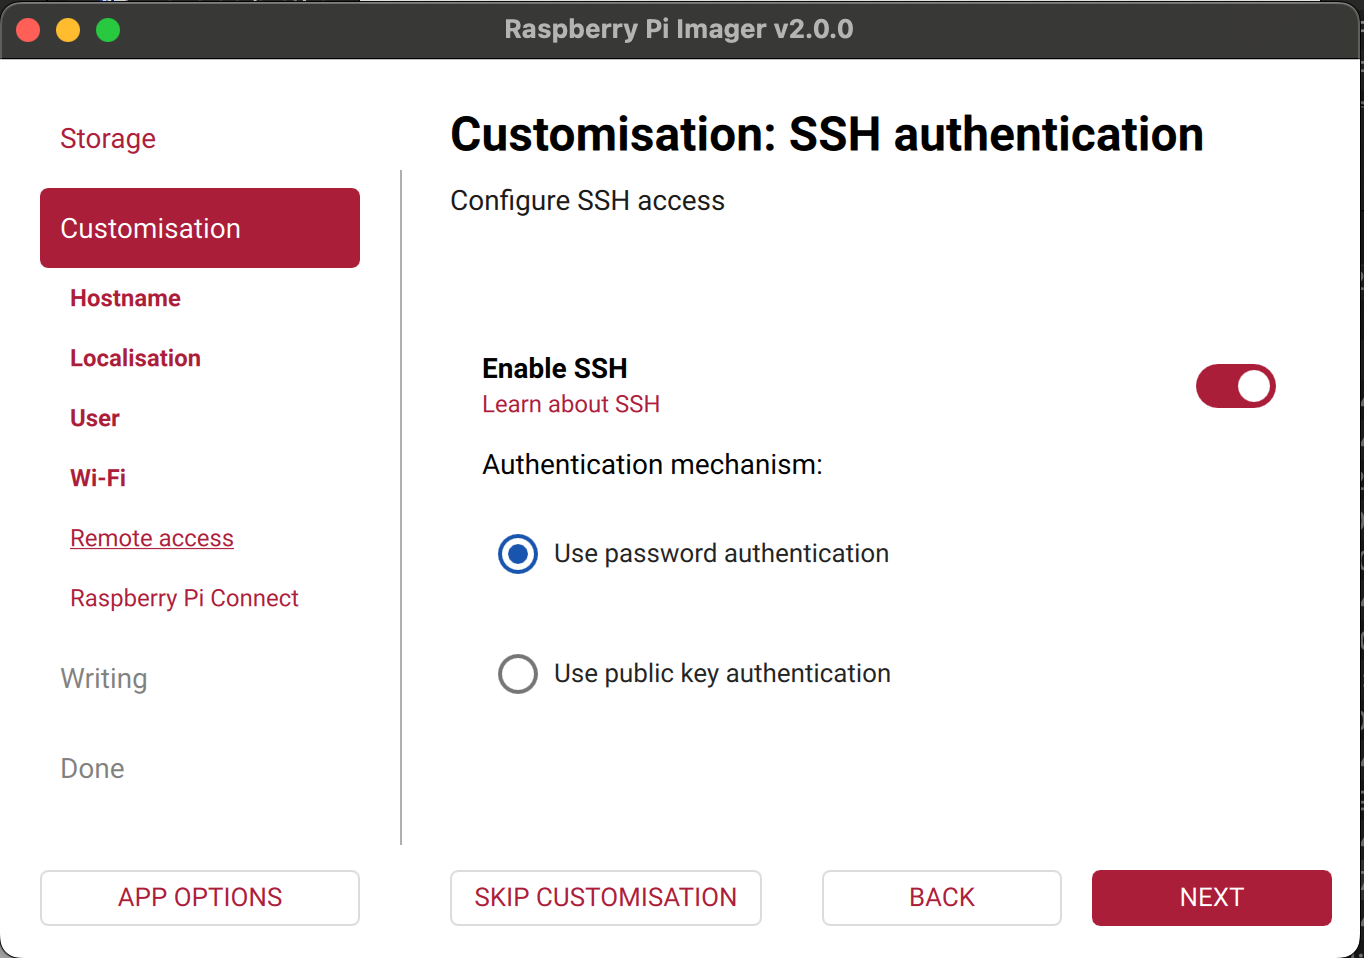
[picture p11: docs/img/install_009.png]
Étape 1.8.1
- 
#### Étape 1.9 : RPI connect optionnel (non recommandé)
- [ ] Cliquer sur **"Customisation: RPI connect"** et cocher "Enable RPI connect".
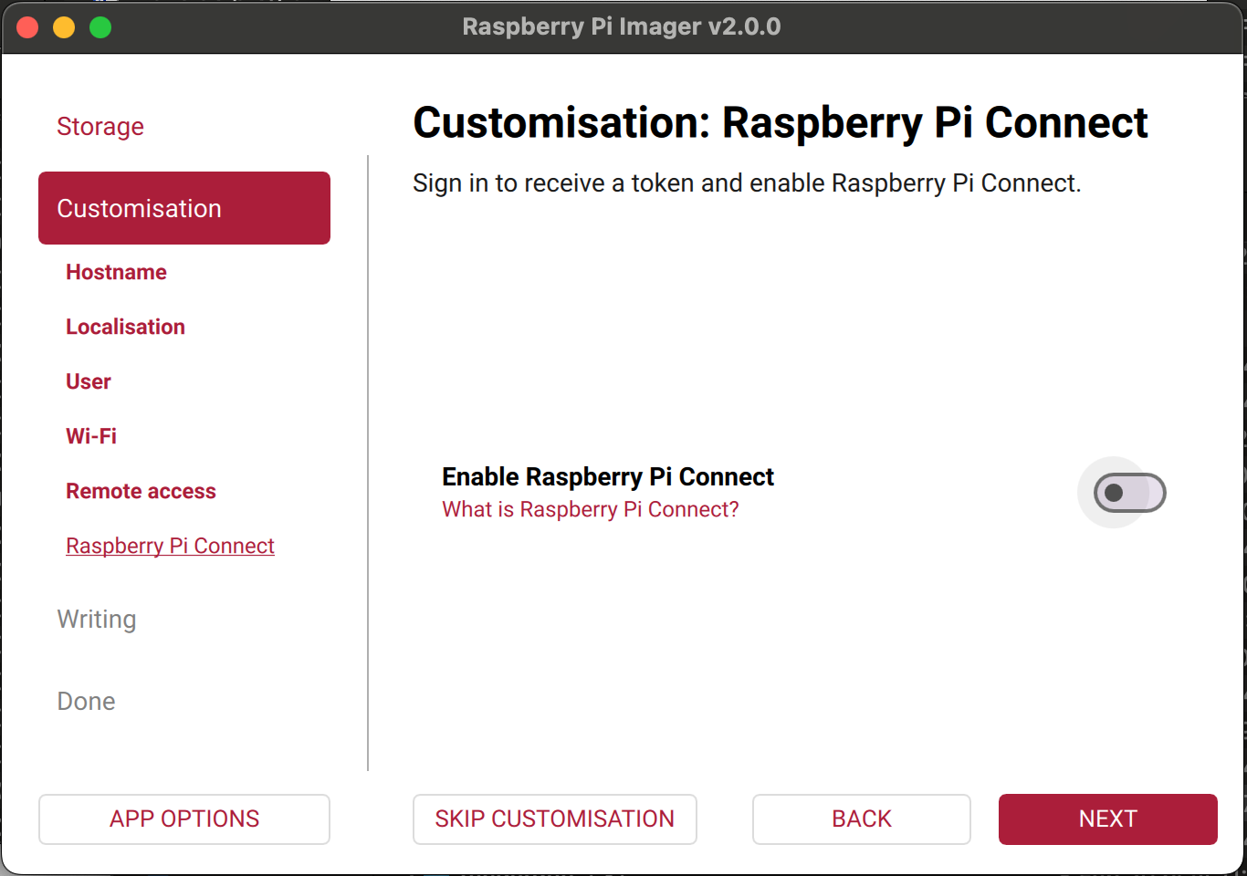
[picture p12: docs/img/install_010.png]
Étape 1.9.1
- 
#### Étape 1.10 : Écriture terminée
- [ ] Cliquer sur **"WRITE"**.
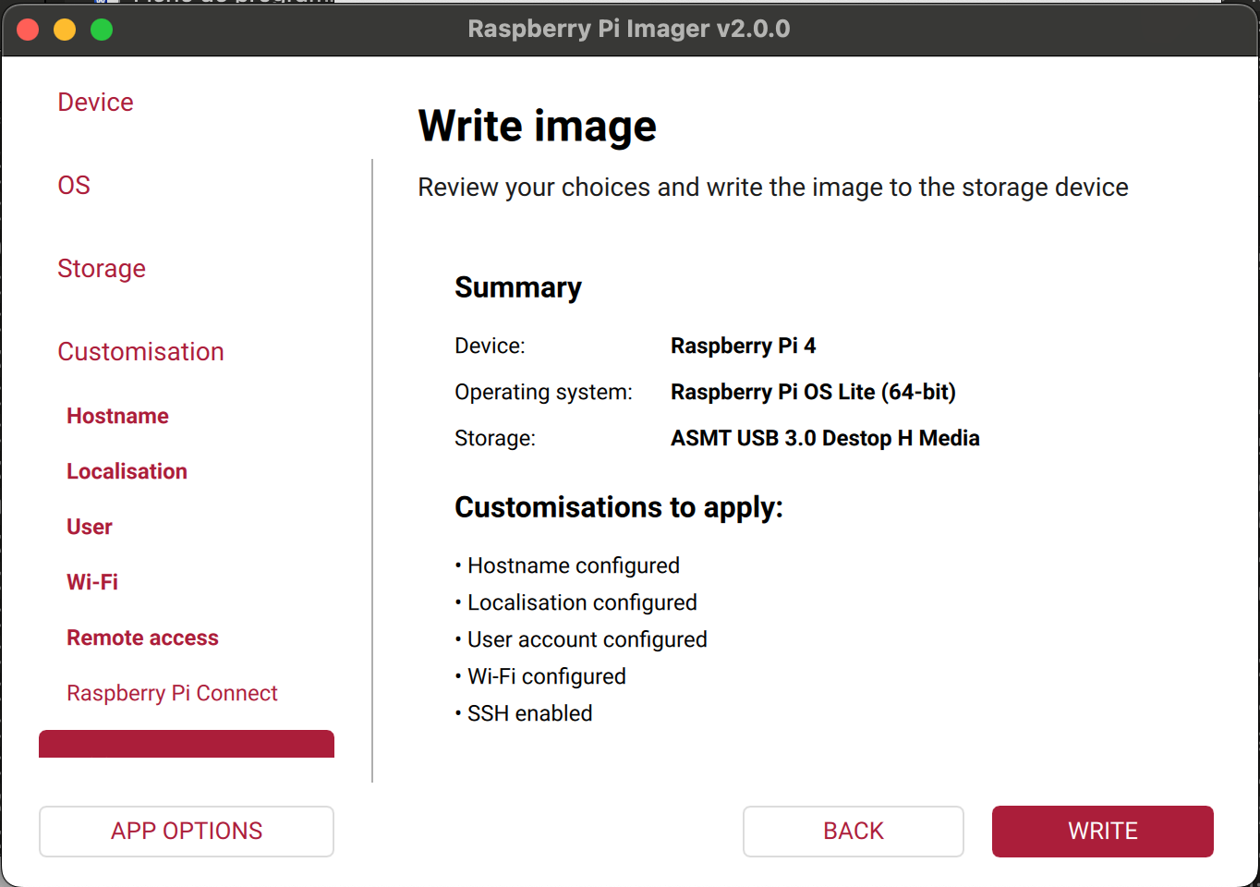
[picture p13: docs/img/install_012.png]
Étape 1.10.1
- 
- [ ] Cliquer sur **"I understand, Erase and write"**.
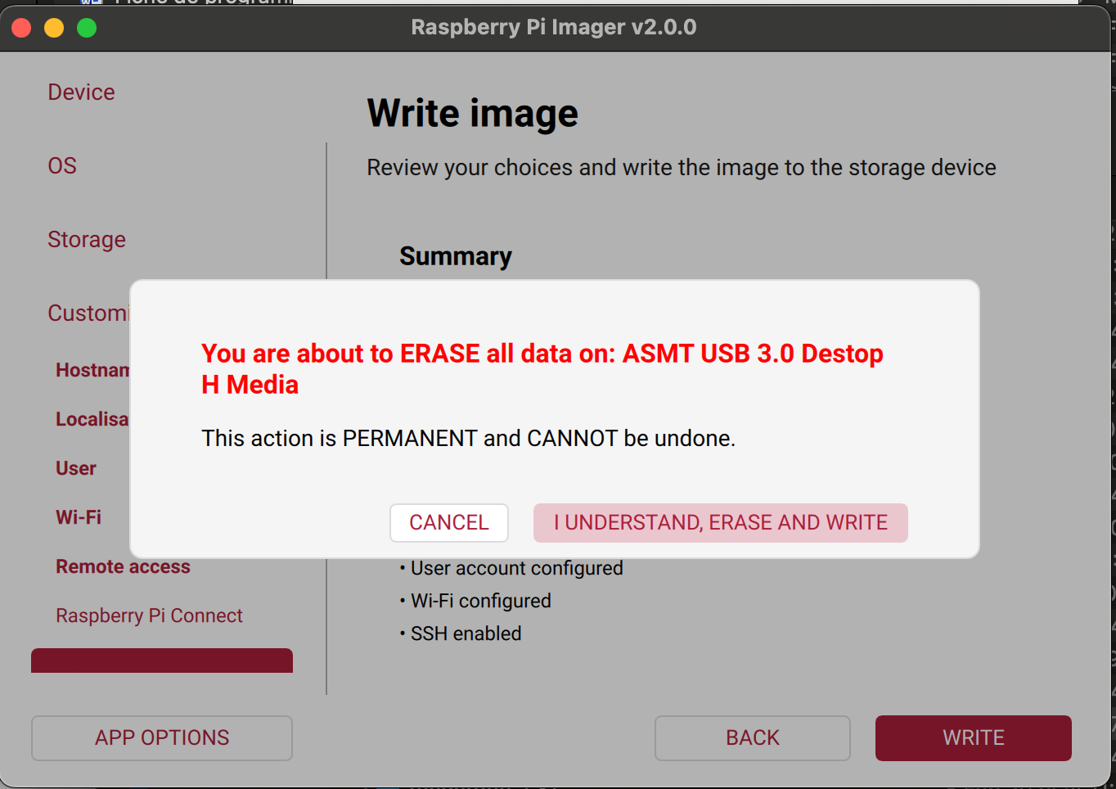
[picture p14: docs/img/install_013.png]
Étape 1.10.2
- 
- [ ] Cliquer sur **"remplir avec le username et passeword admin de la workstation"**.
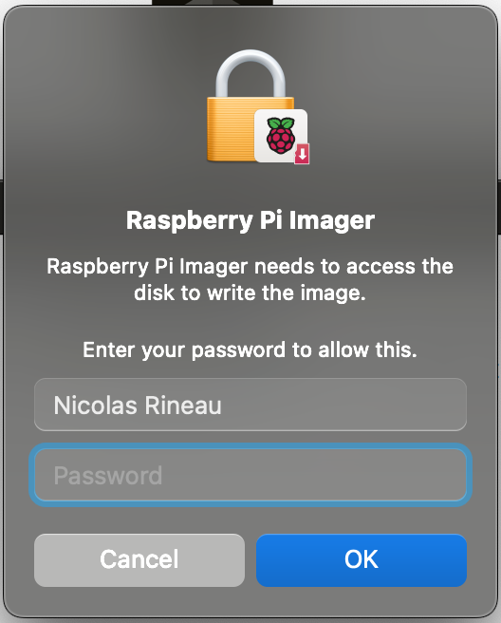
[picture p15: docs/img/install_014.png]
Étape 1.10.3
- 
- [ ] Cliquer sur **"Attendre la fin de l'écriture"**.
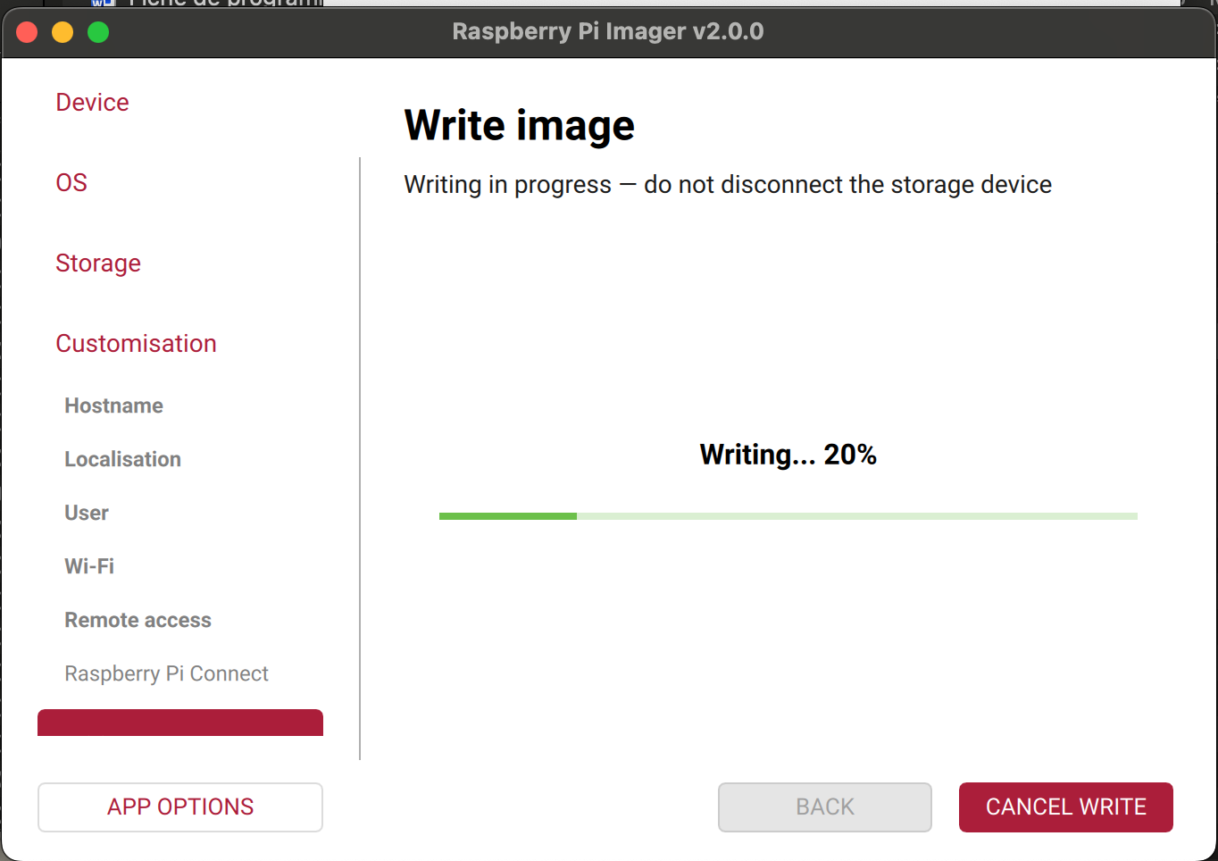
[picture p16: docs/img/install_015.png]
Étape 1.10.4
- 
- [ ] Cliquer sur **"Cliquer sur Finish"**.
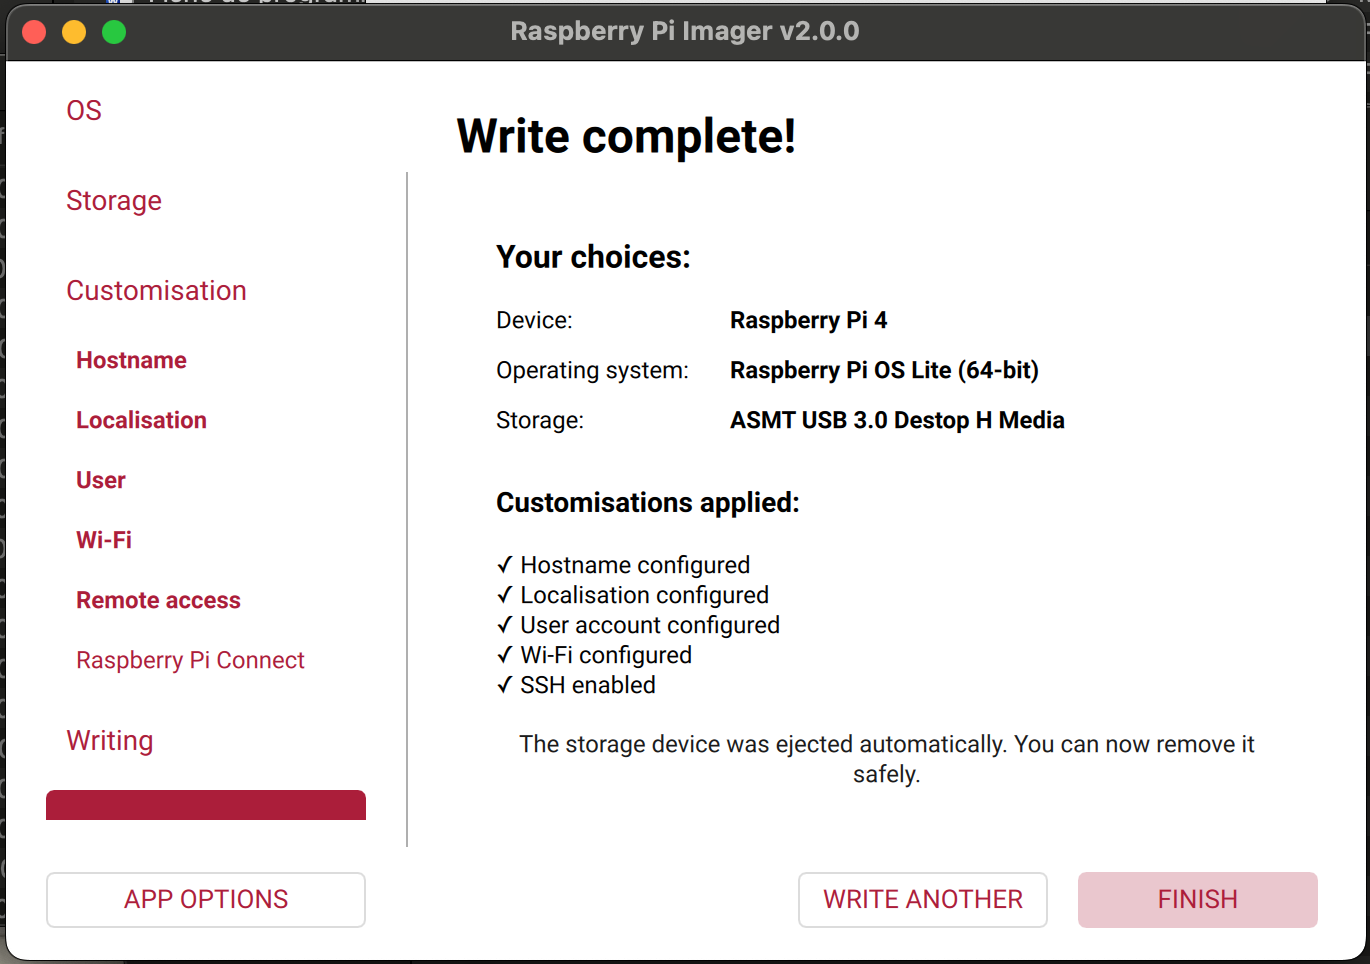
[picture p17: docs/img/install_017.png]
Étape 1.10.5
- 

## Installation sur le Raspberry Pi

### Étape 5 : Brancher le matériel

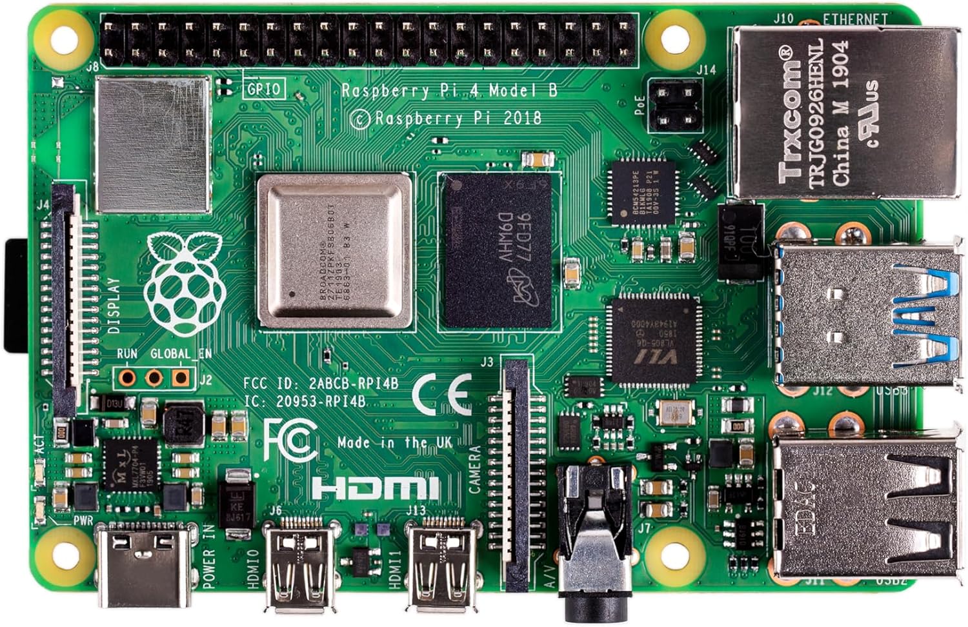
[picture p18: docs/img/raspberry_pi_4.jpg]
Raspberry Pi 4


1. Connecter le **SSD au Raspberry Pi** via l'adaptateur USB-SATA (Port bleu USB 3.0).
2. Connecter le **câble Ethernet**.
3. Connecter l'**alimentation** USB-C.

### Étape 6 : Premier démarrage et IP

1. Allumer le Raspberry Pi et attendre 2 minutes.
2. Depuis votre ordinateur, trouver l'adresse IP du Raspberry Pi :

**Sur le même réseau local :**

```bash
# Linux/Mac
arp -a | grep -i "b8:27:eb\|dc:a6:32\|e4:5f:01"
```

**Via le routeur :**
- Identifier le Raspberry Pi dans la liste des appareils connectés.

---
[:material-arrow-right-circle: **Étape suivante : Choix du Domaine WAN**](wan.md){ .md-button .md-button--primary }

## Dépannage

### Le Raspberry Pi ne démarre pas

- Vérifier que l'alimentation est suffisante (5V, 3A minimum)
- Vérifier que le SSD est correctement connecté
- Vérifier les LEDs du Raspberry Pi

### Impossible de se connecter en SSH

- Vérifier que SSH est activé dans les options de Raspberry Pi Imager
- Vérifier que le Raspberry Pi est sur le même réseau
- Vérifier le pare-feu du routeur

### Le SSD n'est pas détecté

- Vérifier que l'adaptateur USB-SATA est compatible USB 3.0
- Essayer un autre port USB sur le Raspberry Pi
- Vérifier que le SSD est correctement formaté

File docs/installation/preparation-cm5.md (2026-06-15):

# Préparation matérielle — Gateway CM5

## Matériel

- [ ] **Carte Essensys Gateway CM5** (stack 3 PCB + CM5)
- [ ] **Compute Module 5** (4 Go minimum recommandé)
- [ ] **NVMe M.2** (2230/2242) — données applicatives (`/mnt/nvme`)
- [ ] **Alimentation 12–24 V DC** (bornier industriel)
- [ ] **2 câbles Ethernet** (eth0 → routeur LAN, eth1 → armoire)
- [ ] **Montage DIN rail** (enclosure fournie)

Schémas KiCad : `src/cm5/` dans ce dépôt.

## Avant le premier boot

### 1. Activer PCIe / NVMe (firmware CM5)

Le NVMe doit être activé dans l'EEPROM Raspberry Pi (CM5). Sans cette étape, `nvme0n1` n'apparaît pas.

Voir la [documentation officielle Raspberry Pi CM5 + NVMe](https://www.raspberrypi.com/documentation/computers/compute-module.html).

### 2. Partition NVMe

```bash
sudo parted /dev/nvme0n1 -- mklabel gpt
sudo parted /dev/nvme0n1 -- mkpart essensys-data ext4 1MiB 100%
sudo mkfs.ext4 -L essensys-data /dev/nvme0n1p1
```

### 3. Relever les adresses MAC

```bash
ip link show eth0 | awk '/ether/{print $2}'   # -> gateway_eth0_mac (LAN)
ip link show eth1 | awk '/ether/{print $2}'   # -> gateway_eth1_mac (armoire)
```

Ces MAC sont **obligatoires** dans `inventory.gateway` pour un binding stable des interfaces.

## Stockage

| Support | Rôle |
|---|---|
| **eMMC** (`mmcblk0`) | OS Debian ou NixOS, images Docker, config |
| **NVMe** (`/mnt/nvme`) | Redis, logs, Prometheus, données à forte écriture |

## Câblage réseau

| Port | Branchement |
|---|---|
| **eth0** (natif CM5) | Routeur / box Internet (DHCP) |
| **eth1** (USB RTL8153) | Switch ou bus armoire Essensys uniquement |

!!! danger "Ne pas inverser eth0/eth1"
    eth1 n'a **pas** de route par défaut. L'armoire ne doit jamais être branchée sur eth0.

## Suite

- [Installation OS Debian](os-installation.md)
- [Gateway CM5 — guide complet](gateway-cm5.md)

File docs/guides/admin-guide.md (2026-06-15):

# Guide Administrateur — Gateway Essensys

Ce guide couvre l'exploitation technique de la **Gateway CM5** : accès, services,
supervision, sauvegarde et mises à jour.

!!! info "Public visé"
    Administrateur / installateur. Pour l'usage domotique de l'interface, voir le
    [Guide Utilisateur](user-guide.md).

---

## 1. Architecture en bref

La gateway sépare physiquement deux réseaux sur **deux ports RJ45** :

- **eth0** (LAN, DHCP) — frontend HTTPS utilisateurs, SSH, mises à jour.
- **eth1** (`10.0.1.1/24`, statique, isolé) — armoire Essensys (HTTP legacy + DHCP/DNS).

Détails complets : [Installation Gateway CM5](../installation/gateway-cm5.md).

---

## 2. Accès administrateur

### SSH

```bash
ssh essensys@<ip-eth0>      # ex. ssh essensys@192.168.0.14
```

### Interfaces web d'administration

| Service | URL | Réseau | Usage |
|---|-----|---|---|
| Console AdGuard Home | `http://<ip-eth0>:3000/` | eth0 | DNS, filtrage, clients |
| Dashboard Traefik | `http://<ip-eth0>:8080/` | eth0 | Routeurs, services, TLS |
| Prometheus | `http://<ip-eth0>:9092/` | eth0 | Métriques |
| Alertmanager | `http://<ip-eth0>:9093/` | eth0 | Alertes |

<!-- SCREENSHOT: console AdGuard Home (:3000) -->
Console AdGuard Home

<!-- SCREENSHOT: dashboard Traefik (:8080) -->
Dashboard Traefik

---

## 3. Services (stack Docker)

Tous les services tournent en conteneurs avec `network_mode: host`, décrits dans
`/opt/data/docker-compose.yml`.

| Conteneur | Image | Rôle |
|---|---|---|
| `essensys-backend` | `essensyshub/essensys-backend` | API Go (:7070) |
| `essensys-nginx` | `essensyshub/essensys-nginx` | Reverse proxy / frontend (:80) |
| `essensys-traefik` | `essensyshub/essensys-traefik` | Frontend HTTPS WAN/LAN (:443) |
| `essensys-mosquitto` | `essensyshub/essensys-mosquitto` | Bus MQTT (:1883) |
| `essensys-redis` | `essensyshub/essensys-redis` | File d'ordres |
| `essensys-adguard` | `adguard/adguardhome` | DNS + filtrage (eth0) |
| `essensys-mcp` | `essensyshub/essensys-backend` | Serveur MCP (:8083) |
| `essensys-control-plane` | `essensyshub/essensys-control-plane` | Supervision (:9100) |
| `essensys-prometheus` | `prom/prometheus` | Métriques (:9092) |
| `essensys-alertmanager` | `prom/alertmanager` | Alertes (:9093/:9094) |
| `essensys-node-exporter` | `prom/node-exporter` | Métriques hôte (:9101) |
| `essensys-openclaw` | `coollabsio/openclaw` | Automatisation |

### Commandes courantes

```bash
# État de la stack
docker ps

# Logs d'un service
docker logs -f essensys-backend

# Redémarrer un service
docker restart essensys-nginx

# Recharger toute la stack
cd /opt/data && docker compose up -d
```

Voir aussi les pages [Logs Backend](../logs/backend.md), [Logs Nginx](../logs/nginx.md),
[Logs Traefik](../logs/traefik.md).

---

## 4. Réseau armoire (eth1)

```bash
# Baux DHCP attribués aux équipements de l'armoire
sudo cat /var/lib/misc/dnsmasq.leases

# Vérifier la résolution split-DNS côté armoire
dig @10.0.1.1 mon.essensys.fr +short      # -> 10.0.1.1

# Journaux DHCP/DNS
journalctl -u dnsmasq -f
```

Configuration : `/etc/dnsmasq.conf` (plage `10.0.1.100-200`, upstream Quad9).

!!! danger "Isolement armoire"
    Ne **jamais** ajouter de route par défaut sur eth1 ni exposer de service
    supplémentaire sur `10.0.1.1` : cela romprait le cloisonnement de sécurité.

---

## 5. Supervision

- **Prometheus** (`:9092`) collecte les métriques (`node-exporter`, control-plane).
- **Alertmanager** (`:9093`) gère les alertes.
- **Control-plane** (`:9100`) expose l'état des services Essensys.

```bash
# Santé rapide
curl -s http://localhost:7070/health
curl -s http://localhost:9100/        # control-plane
```

<!-- SCREENSHOT: Prometheus ou control-plane -->
Supervision

---

## 6. Stockage NVMe

Les données à forte écriture résident sur le NVMe (`/mnt/nvme`) pour préserver l'eMMC.

```bash
# Occupation
df -h /mnt/nvme/data /mnt/nvme/logs

# Vérifier le montage persistant
findmnt /mnt/nvme
```

| Chemin NVMe | Contenu |
|---|---|
| `/mnt/nvme/data` | `data_dir`, Redis, TSDB Prometheus |
| `/mnt/nvme/logs` | Journaux applicatifs |

---

## 7. Accès WAN et authentification

L'accès depuis Internet passe par Traefik (HTTPS + authentification). Seul
`/api/admin/inject` est exposé en WAN ; les autres API sont bloquées (403).
Détails : [Accès WAN](../acces/wan.md), [Architecture Traefik](../architecture/traefik.md).

---

## 8. Mises à jour

```bash
# Mise à jour de la stack Essensys
sudo /opt/.../update.sh        # script update.sh du dépôt

# Tirer une version d'image précise (ex. V.1.3.0)
cd /opt/data && docker compose pull && docker compose up -d
```

Voir [Maintenance — Mise à jour](../maintenance/update.md).

---

## 9. Dépannage rapide

| Symptôme | Vérification |
|---|---|
| Frontend HTTPS inaccessible | `docker ps | grep traefik` ; `ss -tlnp | grep :443` |
| Armoire ne joint plus la gateway | `journalctl -u dnsmasq` ; `ip -br addr show eth1` |
| API legacy KO | conf Nginx armoire (`proxy_buffering`, `gzip off`) — [Architecture Nginx](../architecture/nginx.md) |
| NVMe absent | `lsblk` ; firmware PCIe ; `findmnt /mnt/nvme` |
| eth0/eth1 inversés | `Match` par MAC dans `/etc/systemd/network/*.network` |

Voir aussi [Dépannage](../maintenance/troubleshooting.md) et [Interface de Débogage](../maintenance/debug.md).
</content>

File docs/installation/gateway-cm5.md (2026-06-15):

# Installation Gateway CM5 (double attache réseau)

La **Gateway Essensys** est la nouvelle plateforme matérielle bâtie autour d'un
**Raspberry Pi Compute Module 5 (CM5)**. Elle apporte un **niveau de sécurité
supérieur** par rapport à l'installation Raspberry Pi 4 mono-interface : le trafic
**utilisateur** et le trafic **armoire Essensys** sont **physiquement séparés** sur
**deux ports Ethernet (RJ45)** distincts.

!!! info "À qui s'adresse cette page"
    Cette page décrit l'installation **double attache réseau** (« dual-NIC »), le
    profil recommandé pour les déploiements en production. Pour l'installation
    historique mono-interface sur Raspberry Pi 4, voir
    [Installation standard](index.md). Pour la variante **NixOS**, voir
    [Préparation NixOS — Gateway CM5](nixos-cm5.md).

---

## 1. Principe : deux ports RJ45, deux réseaux

| Port | Réseau | Rôle | Exemple réel |
|---|---|---|---|
| **eth0** (natif CM5) | **LAN / utilisateurs** | Accès au frontend en **HTTPS** (Traefik :443), administration, mises à jour, SSH. Client **DHCP** du routeur amont. | `192.168.0.14/23` |
| **eth1** (USB RTL8153) | **Armoire Essensys** | Réseau **privé isolé** dédié au bus d'équipements. La gateway y est **serveur DHCP + DNS** et y expose l'**API legacy en HTTP** (Nginx :80, compatibilité `BP_MQX_ETH`). **IP statique, sans route par défaut.** | `10.0.1.1/24` |

L'intérêt de sécurité est double :

- **Cloisonnement** : l'armoire et ses équipements ne sont **jamais exposés** sur le
  LAN utilisateur ni sur Internet. Le segment `eth1` n'a **pas de route par défaut**.
- **Surface réduite** : seul `eth0` porte le frontend HTTPS et l'accès distant ;
  l'armoire ne voit que ce dont le firmware a besoin (HTTP :80 + DHCP/DNS).

```mermaid
graph LR
    subgraph LAN["LAN utilisateurs (192.168.0.0/23)"]
        Router[Routeur / Box<br/>192.168.0.1]
        UserPC[Navigateur utilisateur<br/>mon.essensys.local]
    end

    subgraph GW["Gateway CM5"]
        eth0[eth0<br/>192.168.0.14<br/>DHCP client]
        eth1[eth1<br/>10.0.1.1/24<br/>IP statique]
        Traefik[Traefik :443<br/>HTTPS frontend]
        NginxLan[Nginx :80<br/>eth0]
        NginxArm[Nginx :80<br/>eth1 - API legacy]
        Dnsmasq[dnsmasq<br/>DHCP + DNS eth1]
        Avahi[avahi / mDNS<br/>mon.essensys.local]
    end

    subgraph ARM["Armoire Essensys (10.0.1.0/24 - isolé)"]
        Client[Client BP_MQX_ETH<br/>DHCP 10.0.1.100-200]
    end

    Router --- eth0
    UserPC -->|mon.essensys.local| Avahi
    UserPC -->|HTTPS| Traefik
    eth0 --- Traefik
    eth0 --- NginxLan
    eth0 --- Avahi
    eth1 --- NginxArm
    eth1 --- Dnsmasq
    Client -->|DHCP / DNS| Dnsmasq
    Client -->|HTTP mon.essensys.fr :80| NginxArm

    style GW fill:#e8f5e9
    style LAN fill:#e3f2fd
    style ARM fill:#fff4e1
```

---

## 2. Résolution de nom : deux domaines, une seule gateway

La gateway répond sous **deux noms** selon le côté du réseau :

| Côté | Nom | Résolution | Mécanisme |
|---|-----|---|---|
| **LAN utilisateurs (eth0)** | `mon.essensys.local` | → `192.168.0.14` (IP eth0) | **mDNS** via `avahi-publish` (aucune config DNS côté client) |
| **Armoire (eth1)** | `mon.essensys.fr` | → `10.0.1.1` (IP eth1) | **split-DNS** `dnsmasq` (`address=/mon.essensys.fr/10.0.1.1`) |

!!! note "Pourquoi deux noms ?"
    Le firmware historique de l'armoire (`BP_MQX_ETH`) interroge `mon.essensys.fr`
    en HTTP : sur le segment armoire, ce nom **doit** pointer vers la gateway
    (`10.0.1.1`). Côté utilisateurs, `mon.essensys.local` est diffusé en mDNS,
    ce qui évite toute configuration DNS sur les postes du LAN.

---

## 3. Matériel et stockage (eMMC + NVMe)

La CM5 sépare aussi le **stockage** pour préserver l'eMMC de l'usure :

| Support | Périphérique | Contenu |
|---|---|---|
| **eMMC interne** | `mmcblk0` (~29 Go) | OS (Debian 13 « trixie »), paquets, images de conteneurs, configuration statique, bootloader. |
| **NVMe SSD** | `nvme0n1` → `/mnt/nvme` (label `essensys-data`) | Données « vivantes » à forte écriture : `/mnt/nvme/data` (`data_dir`), `/mnt/nvme/logs`, bases Redis, TSDB Prometheus, journaux applicatifs. |

Vérification rapide sur la gateway :

```bash
lsblk -o NAME,SIZE,TYPE,MOUNTPOINT,LABEL
# mmcblk0  29.1G ... /                rootfs
# nvme0n1 119.2G ... /mnt/nvme        essensys-data
findmnt /mnt/nvme
```

!!! warning "Pré-requis firmware CM5"
    Le **NVMe (PCIe)** doit être activé dans l'EEPROM de la CM5 et le `BOOT_ORDER`
    adapté. Cette étape n'est pas automatisable et doit être réalisée au premier
    flash — voir la documentation Raspberry Pi officielle pour CM5 + NVMe.

---

## 4. Configuration réseau réelle (référence)

Les fichiers ci-dessous sont générés par le rôle Ansible
`raspberry_gateway_network` et reproduits ici pour référence.

### eth0 — LAN (`/etc/systemd/network/10-eth0.network`)

```ini
[Match]
MACAddress=88:a2:9e:34:27:61   # MAC réelle de eth0
Name=eth0

[Network]
DHCP=ipv4
IPv6AcceptRA=no
LinkLocalAddressing=no

[DHCP]
RouteMetric=10
UseDNS=false
UseDomains=false
```

### eth1 — Armoire (`/etc/systemd/network/20-eth1.network`)

```ini
[Match]
MACAddress=00:e0:4c:68:01:be   # MAC réelle de eth1 (USB RTL8153)
Name=eth1

[Network]
Address=10.0.1.1/24
IPv6AcceptRA=no
LinkLocalAddressing=no
ConfigureWithoutCarrier=yes
# Pas de route par defaut sur eth1 -> isolement du segment armoire
```

!!! tip "Nommage stable des interfaces"
    Les interfaces sont appariées **par adresse MAC** (`Match`), ce qui garantit
    que `eth0`/`eth1` ne s'inversent jamais entre deux redémarrages. Relevez vos
    MAC réelles avec `ip link show` avant de remplir l'inventaire.

### DHCP + DNS armoire (`/etc/dnsmasq.conf`)

```ini
interface=eth1
bind-interfaces
listen-address=10.0.1.1
no-dhcp-interface=eth0
no-resolv
server=9.9.9.9                       # upstream DNS (Quad9)
address=/mon.essensys.fr/10.0.1.1    # split-DNS armoire -> gateway
dhcp-range=10.0.1.100,10.0.1.200,12h
dhcp-option=6,10.0.1.1               # DNS poussé = la gateway
dhcp-option=3                        # aucune passerelle poussée (isolement)
log-dhcp
```

`dnsmasq` est **strictement lié à eth1** (`bind-interfaces` + `listen-address`),
il n'entre donc **jamais en conflit** avec AdGuard Home qui sert le DNS sur eth0.

### Diffusion mDNS LAN (`avahi-publish-essensys.service`)

```ini
ExecStart=/usr/bin/avahi-publish -a -R mon.essensys.local 192.168.0.14
```

---

## 5. Répartition des ports (binding par interface)

Avec `network_mode: host`, chaque service écoute sur une adresse IP précise. Voici
le mappage **réel** observé sur la gateway (`ss -tlnp`) :

| Service | Écoute | Interface | Rôle |
|---|---|---|---|
| Traefik | `192.168.0.14:443` | eth0 | Frontend **HTTPS** utilisateurs |
| Nginx | `192.168.0.14:80` | eth0 | Frontend / API local LAN |
| Nginx | `10.0.1.1:80` | **eth1** | **API legacy armoire** (`BP_MQX_ETH`) |
| AdGuard Home | `192.168.0.14:53` | eth0 | DNS LAN + filtrage |
| AdGuard Home | `192.168.0.14:3000` | eth0 | Console d'administration AdGuard |
| dnsmasq | `10.0.1.1:53` | **eth1** | DNS + DHCP armoire |
| Backend Go | `:7070` | toutes | API backend (proxifiée) |
| MQTT (Mosquitto) | `:1883` | toutes | Bus MQTT |
| Traefik dashboard | `:8080` / `:8081` | toutes | Dashboard / API interne Traefik |
| MCP | `:8083` | toutes | Serveur MCP (pilotage IA) |
| Prometheus | `:9092` | toutes | Métriques |
| Alertmanager | `:9093` / `:9094` | toutes | Alertes |
| Control-plane | `:9100` | toutes | Plan de contrôle / supervision |
| node-exporter | `:9101` | toutes | Métriques hôte |

!!! danger "Ne pas casser le mode single-packet TCP"
    Le client legacy `BP_MQX_ETH` exige une réponse HTTP **en un seul paquet TCP**.
    La configuration Nginx (`proxy_buffering`, `gzip off`) ne doit pas être modifiée
    sur le chemin armoire (`10.0.1.1:80`). Voir [Architecture Nginx](../architecture/nginx.md).

---

## 6. Déploiement

Tous les déploiements passent par le dépôt **`essensys-ansible`** (les anciens
scripts `install.sh` / `update.sh` de `essensys-raspberry-install` sont remplacés
par des playbooks Ansible). La Gateway CM5 a **deux systèmes possibles** :

| OS | Playbook | État | Quand l'utiliser |
|----|---|---|---|
| **Debian 13 + Docker** | `install.gateway.yml` | Profil de production actuel | Déploiement standard de la gateway. |
| **NixOS** | `prepare.nixos-cm5.yml` puis `nixos-install` | Variante déclarative | Voir [Préparation NixOS — Gateway CM5](nixos-cm5.md). |

### 6.1 Debian + Docker (recommandé)

Le playbook `install.gateway.yml` active le profil gateway (`gateway_dual_nic: true`)
et enchaîne, **dans cet ordre**, le stockage NVMe → le réseau dual-NIC → le DHCP/DNS
armoire, puis les rôles applicatifs habituels :

```bash
cd essensys-ansible

# Inventaire dédié à la gateway (MAC, eth1 IP, plage DHCP, NVMe...)
ansible-playbook install.gateway.yml -i inventory.gateway
```

Rôles spécifiques au profil gateway (en tête de playbook) :
`raspberry_gateway_nvme` → `raspberry_gateway_network` → `raspberry_gateway_dhcp`
→ `raspberry_avahi` (mDNS `mon.essensys.local`).

### 6.2 Variables d'inventaire (`inventory.gateway`)

| Variable | Exemple | Description |
|---|---|---|
| `gateway_dual_nic` | `true` | Active le profil double attache (sinon mono-interface). |
| `gateway_eth0_mac` | `88:a2:9e:34:27:61` | **Obligatoire.** MAC de eth0 (LAN). |
| `gateway_eth1_mac` | `00:e0:4c:68:01:be` | **Obligatoire.** MAC de eth1 (armoire). |
| `gateway_eth0_ip` | `""` | IP eth0 ; vide = auto-détection (`ansible_default_ipv4`). |
| `gateway_eth1_ip` / `gateway_eth1_prefix` | `10.0.1.1` / `24` | IP statique + préfixe sur le segment armoire. |
| `gateway_armoire_hostname` | `mon.essensys.fr` | Nom résolu par le firmware legacy `BP_MQX_ETH`. |
| `gateway_dhcp_range_start` / `_end` | `10.0.1.100` / `10.0.1.200` | Plage de baux DHCP armoire. |
| `gateway_dhcp_lease_time` | `12h` | Durée des baux. |
| `gateway_upstream_dns` | `9.9.9.9` | DNS amont (Quad9). |
| `gateway_dhcp_reservations` | `[]` | Réservations statiques (en `host_vars`). |
| `gateway_nvme_device` | `/dev/nvme0n1` | Périphérique NVMe. |
| `essensys_nvme_mount` | `/mnt/nvme` | Préfixe de montage NVMe (source unique de vérité). |
| `gateway_nvme_bind_mounts_enabled` | `true` | Active les bind-mounts vers le NVMe. |

!!! tip "Relever les MAC avant le premier déploiement"
    ```bash
    ip link show eth0 | awk '/ether/{print $2}'   # -> gateway_eth0_mac
    ip link show eth1 | awk '/ether/{print $2}'   # -> gateway_eth1_mac
    ```

### 6.3 Désinstallation / migration

```bash
ansible-playbook uninstall.cm5.yml   -i inventory.gateway -e confirm_cm5_uninstall=true
ansible-playbook prepare.nixos-cm5.yml -i inventory.gateway -e confirm_cm5_nixos_prep=true
```

!!! note "Non-régression"
    Le playbook mono-interface `install.raspberrypi.yml` reste **inchangé**. Le
    comportement gateway est **opt-in** : il ne s'active que lorsque
    `gateway_dual_nic: true`.

---

## 7. Checklist de validation matérielle

```bash
# 1. Les deux interfaces sont montées avec les bonnes IP
ip -br addr show
#   eth0  UP  192.168.0.14/23
#   eth1  UP  10.0.1.1/24

# 2. eth1 n'a PAS de route par défaut (isolement)
ip route | grep default        # doit pointer uniquement via eth0

# 3. Bindings par interface
sudo ss -tlnp | grep -E ':80|:443|:53'

# 4. Frontend HTTPS côté LAN
curl -k https://mon.essensys.local/      # -> 200

# 5. DNS + API côté armoire
dig @10.0.1.1 mon.essensys.fr +short     # -> 10.0.1.1
curl -v http://mon.essensys.fr/api/      # depuis le segment armoire

# 6. Stockage NVMe monté et utilisé
findmnt /mnt/nvme
df -h /mnt/nvme/data /mnt/nvme/logs
```

---

## 8. Sécurité — points de vigilance

- **eth1 = réseau d'équipement** : n'exposer sur `10.0.1.1` que le strict nécessaire
  (API armoire HTTP + DHCP/DNS). La console AdGuard (`:3000`) reste sur eth0.
- **eth0 = surface utilisateur** : HTTPS (Traefik), SSH admin, mises à jour.
- **Pas de route par défaut sur eth1** : l'armoire ne peut pas atteindre Internet ni
  le LAN, et inversement le LAN n'atteint pas directement l'armoire.
- **TLS armoire** : `mon.essensys.fr` n'a qu'un enregistrement A privé sur le segment
  armoire ; le chemin documenté y reste **HTTP :80** (legacy). Aucun certificat n'est
  requis côté armoire.

---

## 9. Voir aussi

- [Préparation NixOS — Gateway CM5](nixos-cm5.md) — variante NixOS du même profil.
- [Architecture Nginx](../architecture/nginx.md) — contrainte single-packet TCP.
- [Ports utilisés](../architecture/ports.md) — récapitulatif complet des ports.
- [Guide Administrateur](../guides/admin-guide.md) — exploitation au quotidien.

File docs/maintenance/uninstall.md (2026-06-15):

# Désinstallation

Guide pour désinstaller complètement Essensys du Raspberry Pi.

## Désinstallation automatique

## Gateway CM5 (Ansible)

Pour la **CM5 Essensys** (stack Docker + dual-NIC + NVMe) :

```bash
cd essensys-ansible
ansible-playbook uninstall.cm5.yml -i inventory.gateway \
  -e confirm_cm5_uninstall=true
```

Options :

| Variable | Effet |
|---|---|
| `cm5_remove_nvme_fstab=true` | Retire le montage NVMe du fstab |
| `cm5_wipe_nvme_data=true` | Efface la partition NVMe (**irréversible**) |
| `cm5_remove_docker_packages=true` | Désinstalle Docker |

Voir `essensys-ansible/roles/raspberry_cm5_uninstall/README.md`.

## Migration NixOS CM5

Préparation du flake NixOS (clone, Nix, script repartition eMMC **offline**) :

```bash
ansible-playbook prepare.nixos-cm5.yml -i inventory.gateway \
  -e confirm_cm5_nixos_prep=true
```

Documentation : `essensys-raspberry-gateway/docs/nixos-install-cm5.md` et role `raspberry_cm5_nixos`.

### Script uninstall.sh

Le script `uninstall.sh` automatise la désinstallation complète :

```bash
cd ~/essensys-raspberry-install
sudo ./uninstall.sh
```

Le script va :
1. Demander confirmation
2. Arrêter et désactiver tous les services
3. Supprimer les fichiers de service systemd
4. Supprimer la configuration Nginx
5. Supprimer la configuration Traefik
6. Supprimer les binaires
7. Supprimer les fichiers d'installation
8. Supprimer tous les logs
9. Optionnellement supprimer l'utilisateur et les dépôts

## Désinstallation manuelle

### Arrêter les services

```bash
sudo systemctl stop essensys-backend
sudo systemctl stop traefik
sudo systemctl stop traefik-block-service
sudo systemctl stop nginx
```

### Supprimer les services

```bash
sudo systemctl disable essensys-backend
sudo systemctl disable traefik
sudo systemctl disable traefik-block-service
sudo rm /etc/systemd/system/essensys-backend.service
sudo rm /etc/systemd/system/traefik.service
sudo rm /etc/systemd/system/traefik-block-service.service
sudo systemctl daemon-reload
```

### Supprimer les fichiers

```bash
# Configuration
sudo rm -rf /etc/traefik
sudo rm /etc/nginx/sites-available/essensys
sudo rm /etc/nginx/sites-enabled/essensys

# Installation
sudo rm -rf /opt/essensys

# Logs
sudo rm -rf /var/logs/Essensys
sudo rm -rf /var/log/traefik
sudo rm -f /var/log/nginx/essensys-*.log

# Binaires
sudo rm -f /usr/local/bin/traefik
sudo rm -f /usr/local/bin/traefik-block-service.py
```

### Supprimer l'utilisateur (optionnel)

```bash
sudo userdel -r essensys
```

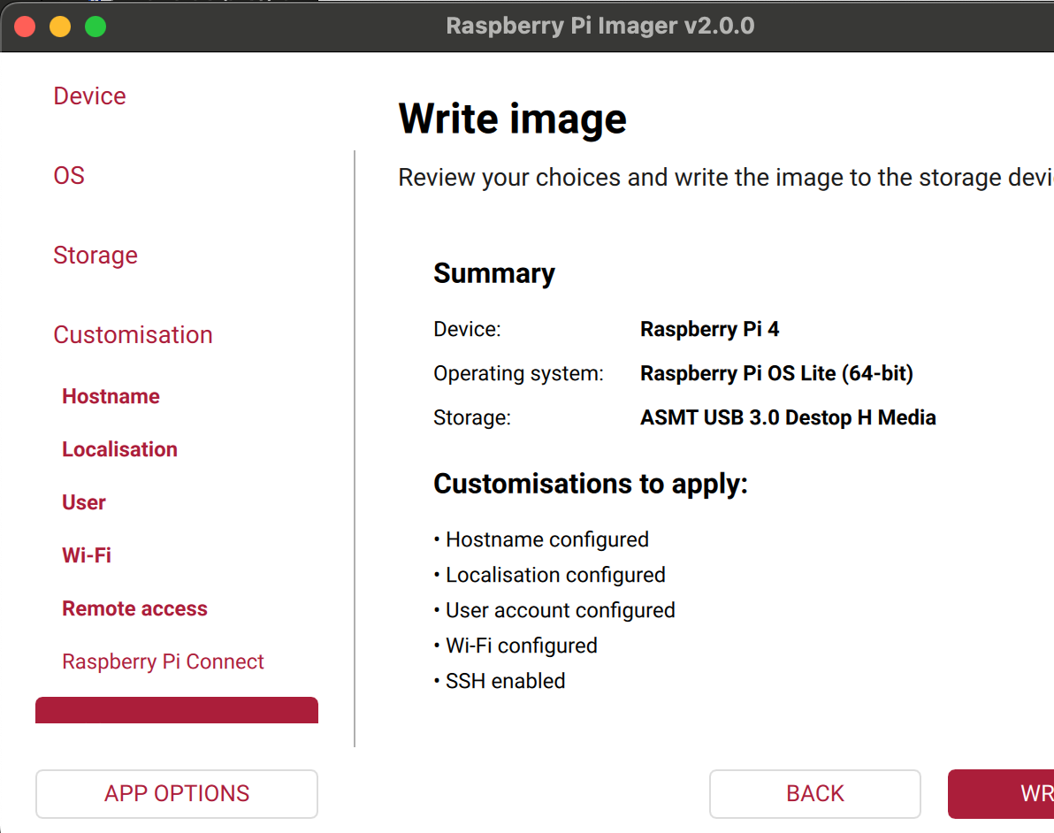
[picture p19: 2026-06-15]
docs/img/install_011.png

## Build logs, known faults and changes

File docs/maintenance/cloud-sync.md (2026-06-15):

# Cloud sync (agent portail distant)

Le module **`internal/cloudsync`** du backend gateway (`essensys-server-backend`) synchronise les actions du portail OVH vers la file locale Redis.

## Activation

`config.yaml` sur la gateway :

```yaml
cloud:
  enabled: true
  hub_url: "https://mon.essensys.fr"
  gateway_id: "gw-essensys-gateway"   # optionnel si dérivé de MAC
  gateway_token: "<token Ansible vault>"
  poll_interval_seconds: 30
```

!!! danger "HTTPS uniquement"
    `hub_url` doit être `https://mon.essensys.fr`. Aucun agent ne doit utiliser `http://` vers le hub WAN.

## Cycle de poll

1. `GET https://mon.essensys.fr/api/gateway/pending-actions` (Bearer + headers MAC)
2. Expansion / injection via `ActionService.AddAction()` (même logique que `/api/admin/inject`)
3. `POST .../api/gateway/actions/{guid}/done` après exécution
4. `POST .../api/gateway/heartbeat` périodique

## Enregistrement OVH

Lors du déploiement Ansible (`portal_backend/register_gateway.yml`) ou manuellement :

```bash
curl -X POST https://mon.essensys.fr/api/portal/admin/gateways/register \
  -H "Authorization: Bearer <admin-jwt>" \
  -H "Content-Type: application/json" \
  -d '{"gateway_id":"gw-...","token":"...","machine_id":19,"eth0_mac":"...","eth1_mac":"..."}'
```

## Logs

```bash
journalctl -u essensys-backend -f | grep -i cloud
docker logs essensys-backend 2>&1 | grep -i cloud
```

## Dépannage

| Symptôme | Cause probable |
|---|---|
| 401 sur pending-actions | Token ou MAC incorrects |
| Aucune action reçue | `machine_id` cloud ≠ actions en file PG |
| Sortie via eth1 | Vérifier route par défaut sur eth0 (`ip route get $(dig +short mon.essensys.fr)`) |
| HTTP dans les logs | Mettre à jour binaire / config `hub_url` |

## Tests

```bash
# Depuis la gateway
./scripts/test-wan-https-ovh.sh https://mon.essensys.fr

# E2E inject (utilisateur avec portal_access)
# essensys-user-portal-frontend/test/e2e_user_portal.sh
```

## Voir aussi

- [Portail remote](../acces/portal-remote.md)
- [Dépannage](troubleshooting.md)

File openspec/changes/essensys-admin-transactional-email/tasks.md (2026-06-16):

## 1. Backend — mailer + database

- [x] 1.1 Extract `internal/notify/mailer.go` from newsletter `sendEmail`
- [x] 1.2 Add migration `006_email_templates.sql` (`email_templates`, `email_send_log`)
- [x] 1.3 Implement `EmailTemplateStore` CRUD in `internal/data/`
- [x] 1.4 Template renderer with allowlisted variables
- [x] 1.5 Seed default templates (`user_welcome`, `device_allocation`, `password_reset`, `role_updated`) — disabled by default
- [x] 1.6 Register routes in `internal/admin/routes.go`
- [x] 1.7 `GET /api/admin/email/health`
- [x] 1.8 `GET|PUT /api/admin/email-templates` and `/{slug}`
- [x] 1.9 `POST /api/admin/email-templates/{slug}/preview`
- [x] 1.10 `POST /api/admin/email-templates/test`
- [x] 1.11 Unit tests: render, SMTP missing, disabled template

## 2. Backend — lifecycle hooks

- [x] 2.1 Hook `CreateUser` → send `user_welcome` when `enabled` + `auto_send`
- [x] 2.2 Hook `UpdateUserLinks` → send `device_allocation` when `enabled` + `auto_send`
- [x] 2.3 `POST /api/admin/users/{id}/resend-email`
- [x] 2.4 Audit log: `EMAIL_SENT`, `EMAIL_SEND_FAILED`
- [x] 2.5 Write rows to `email_send_log` on every attempt
- [ ] 2.6 Integration test with mock SMTP or env guard

## 3. Admin UI — `essensys-support-site/site`

- [x] 3.1 Add tab `email-templates` in `Admin.jsx`
- [x] 3.2 Create `EmailTemplates.jsx` (list, edit subject/body, auto_send toggle, preview, test send)
- [x] 3.3 Add « Renvoyer email » button + modal in `UserManager.jsx`
- [x] 3.4 SMTP health banner when `/api/admin/email/health` reports misconfiguration
- [x] 3.5 French labels consistent with existing admin UI
- [ ] 3.6 Build smoke test on `/admin`

## 4. Ops and documentation

- [ ] 4.1 Verify `vault_smtp_*` on VPS (`/opt/essensys/cloud-backend/.env`)
- [x] 4.2 Update `essensys-user-portal-backend/docs/deployment.md` (transactional vs newsletter)
- [x] 4.3 Update `essensys-support-site/docs/configuration.md` if needed
- [ ] 4.4 Enable `user_welcome.auto_send` after operator validates template copy

## 5. Phase 2 (post-MVP)

- [ ] 5.1 `POST /api/auth/forgot-password` with `password_reset` template
- [ ] 5.2 `role_updated` auto-send on `PUT /api/admin/users/{id}/role`
- [ ] 5.3 Rate limiting on resend endpoint
- [ ] 5.4 HTML wrapper / Essensys branding

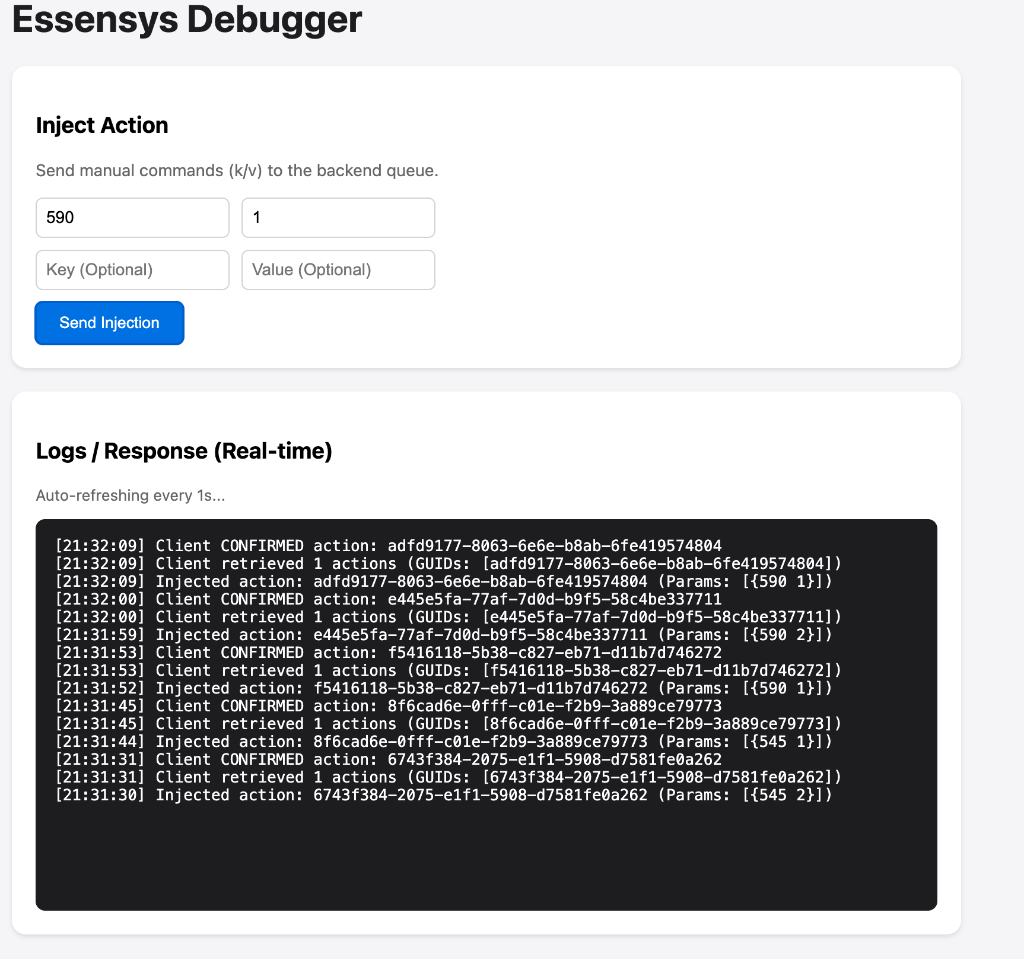
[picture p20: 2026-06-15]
docs/img/debug-interface.png

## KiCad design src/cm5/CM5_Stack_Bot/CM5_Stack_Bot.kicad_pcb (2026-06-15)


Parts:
C9, C18: 100n; C_0402_1005Metric; Part Description 0.1uF 10% 16V Ceramic Capacitor X7R 040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
H1, H2, H3, H4, H5, H6, H7, H8: MountingHole; MountingHole_2.7mm_M2.5_DIN965; Part Description M2.5 mounting hole; not fitted
J11: USB_C_Receptacle_USB2.0; USB_C_Receptacle_GCT_USB4105-xx-A_16P_TopMnt_Horizontal; Part Description USBC USB2 data and power connector
R9: 2.2K 1%; R_0402_1005Metric; Part Description Resistor 2.2K M1005 1% 63mW

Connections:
/+5v: C9.1, C18.1, J11.A4 (VBUS), J11.A9 (VBUS), J11.B4 (VBUS), J11.B9 (VBUS), R9.1; also elsewhere on the board
/CC1: J11.A5 (CC1); also elsewhere on the board
/CC2: J11.B5 (CC2); also elsewhere on the board
/USB2_N: J11.A7 (D-), J11.B7 (D-); also elsewhere on the board
/USB2_P: J11.A6 (D+), J11.B6 (D+); also elsewhere on the board
GND: C9.2, C18.2, J11.A1 (GND), J11.A12 (GND), J11.B1 (GND), J11.B12 (GND), J11.S1 (SHIELD), R9.2; also elsewhere on the board

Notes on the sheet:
Connectors ------- Ethernet SDCARD 40way RPI Jumpers Fan Battery
Connectors ------ M2 MKey
Discharge Resistor Needed by some Type C PSUs
TypeC Power connector
Connectors ------- HDMI 0 HDMI 1 CSI/DSI 0 CSI/DSI 1

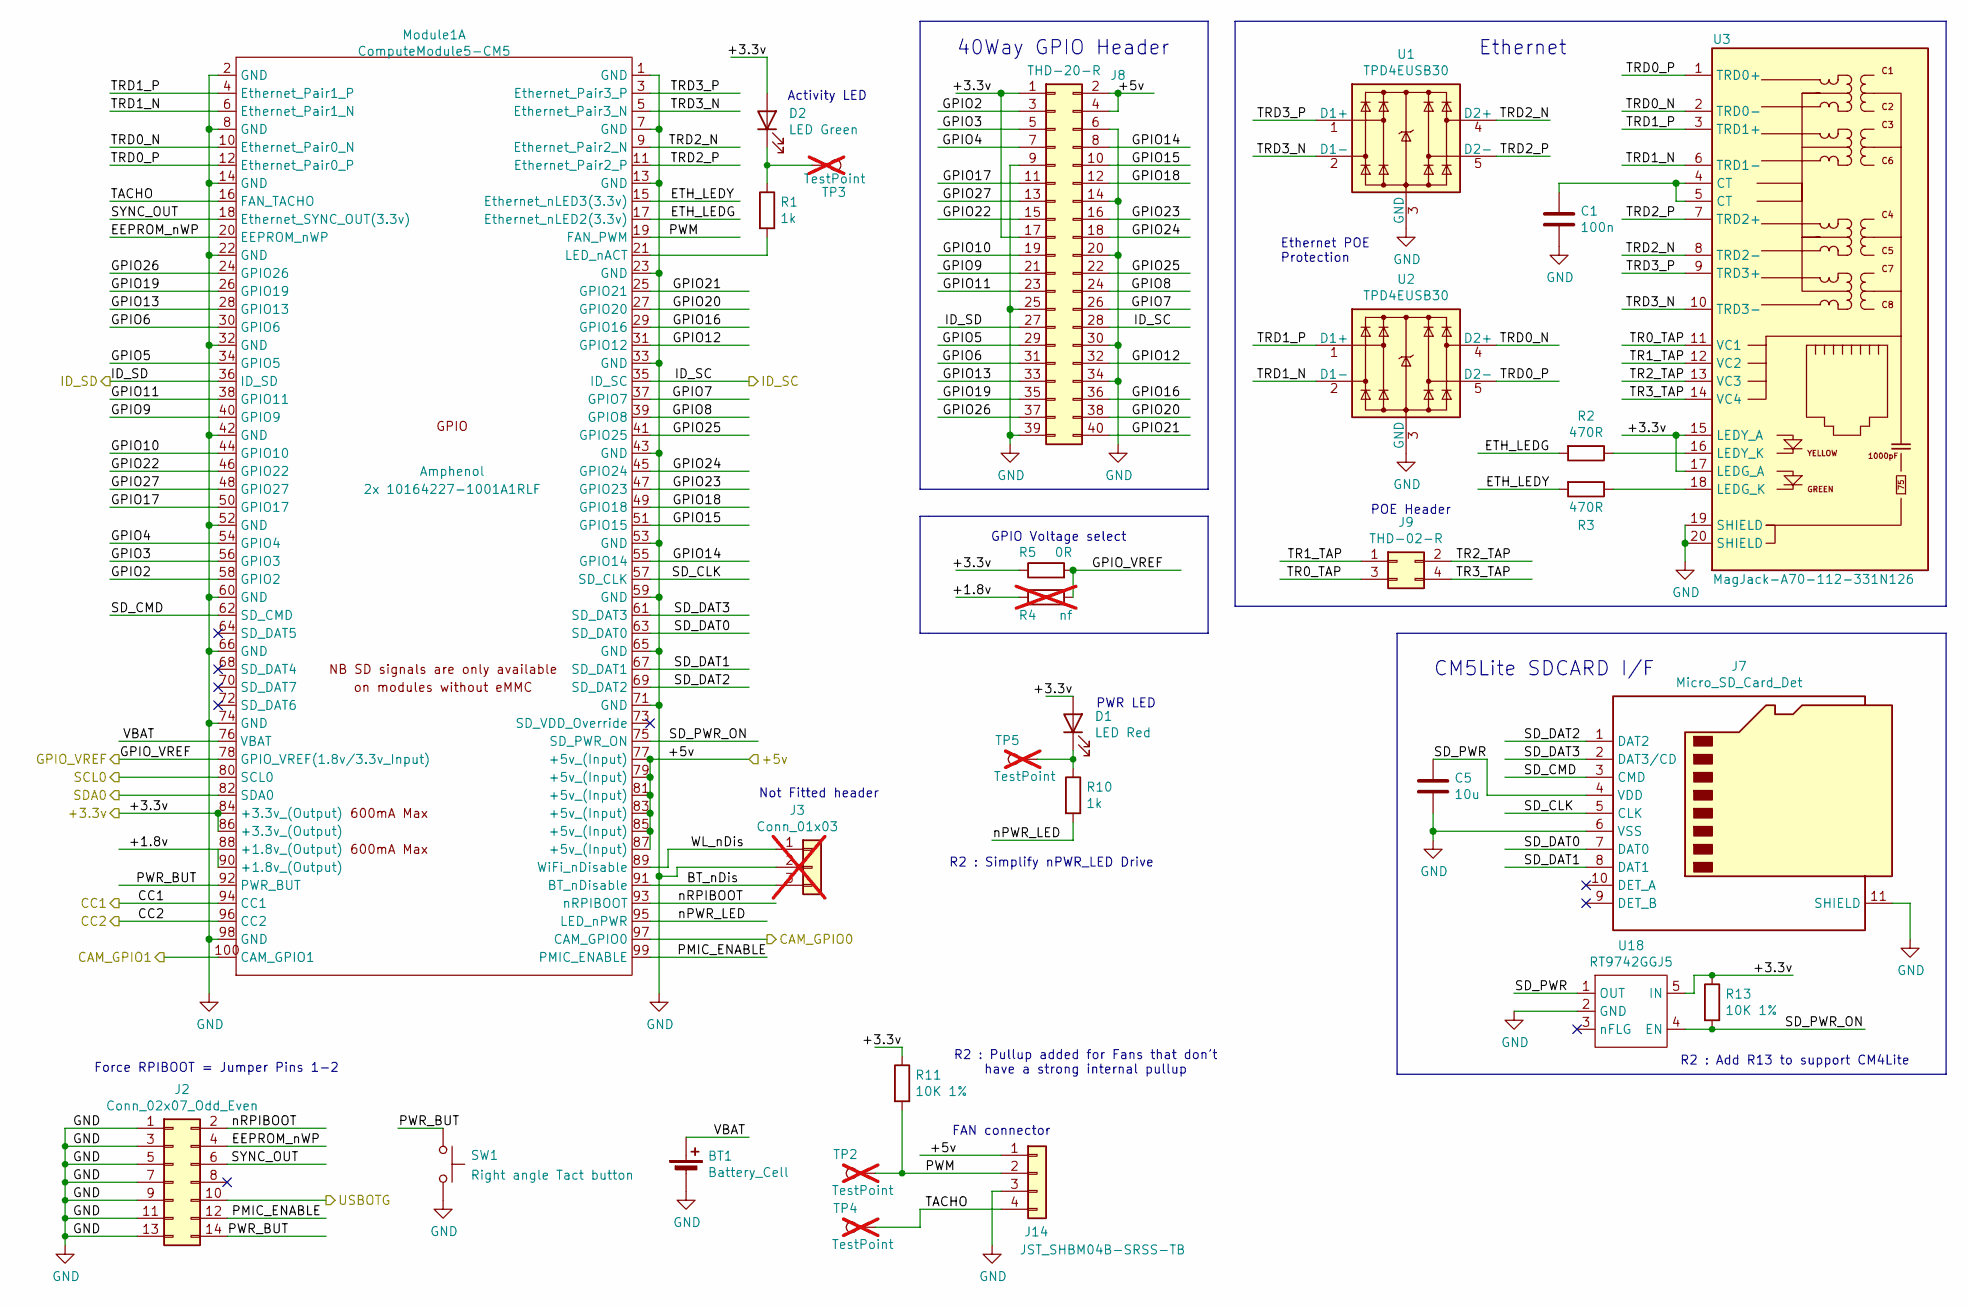
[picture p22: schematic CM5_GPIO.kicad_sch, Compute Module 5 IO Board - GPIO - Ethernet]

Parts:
BT1: Battery_Cell; BatteryHolder_Keystone_3034_1x20mm; Part Description Battery Retainer Coin, 20.0mm 1 Cell SM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
C1: 100n; C_0402_1005Metric; Part Description 0.1uF 10% 16V Ceramic Capacitor X7R 040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
C5: 10u; C_0805_2012Metric; Part Description 10uF 10% 10V Ceramic Capacitor X7R 0805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
D1: LED Red; LED_0603_1608Metric; Part Description Red 620nm LED Indication - Discrete 2.2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
D2: LED Green; LED_0603_1608Metric; Part Description Green 572nm LED Indication - Discrete 2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
J2: Conn_02x07_Odd_Even; PinHeader_2x07_P2.54mm_Vertical; Part Description PinHeader_2x07_P2.54mm_Vertical
J3: Conn_01x03; PinHeader_1x03_P2.54mm_Vertical; Part Description 3pin 0.1" connector; not fitted
J7: Micro_SD_Card_Det; SDCARD_MOLEX_503398-1892; Part Description 9 (8 + 1) Position Card Connector micro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
J8: THD-20-R; PinHeader_2x20_P2.54mm_Vertical; Part Description PinHeader_2x20_P2.54mm_Vertical
J9: THD-02-R; PinHeader_2x02_P2.54mm_Vertical; Part Description PinHeader_2x02_P2.54mm_Vertical
J14: JST_SHBM04B-SRSS-TB; JST_SH_BM04B-SRSS-TB_1x04-1MP_P1.00mm_Vertical; Part Description 4 pin vertical 1mm pitch connector
Module1: ComputeModule5-CM5; Raspberry-Pi-5-Compute-Module; Part Description 100 Position Connector Receptacle, Cent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
R1, R10: 1k; R_0402_1005Metric; Part Description Resistor 1K M1005 1% 63mW
R2, R3: 470R; R_0402_1005Metric; Part Description Resistor 470R M1005 1% 63mW
R4: nf; R_0805_2012Metric_Pad1.20x1.40mm_HandSolder; not fitted
R5: 0R; R_0805_2012Metric_Pad1.20x1.40mm_HandSolder; Part Description Resistor 0R M2012 5%
R11, R13: 10K 1%; R_0402_1005Metric; Part Description Resistor 10K M1005 1% 63mW
SW1: Right angle Tact button; SW_Tactile_SPST_Angled_PTS645Vx58-2LFS; Part Description Right angle through hole Tact switch
TP2, TP3, TP4, TP5: TestPoint; TestPoint_Pad_2.0x2.0mm; Part Description Test point; not fitted
U1, U2: TPD4EUSB30; USON-10_2.5x1.0mm_P0.5mm; Part Description Quad TVS diode for high speed signals (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
U3: MagJack-A70-112-331N126; TRJG0926HENL; Part Description Gigabit Ethernet Magjack
U18: RT9742GGJ5; SOT-23-5; Part Description Power Switch/Driver 1:1 N-Channel 1A TS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

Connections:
/+3.3v: D1.2 (A), D2.2 (A), J8.1, J8.17, Module1.84 (+3.3v_(Output)), Module1.86 (+3.3v_(Output)), R5.1, R11.1, R13.1, U3.15 (LEDY_A), U3.17 (LEDG_A), U18.5 (IN); also elsewhere on the board
/+5v: J8.2, J8.4, J14.1, Module1.77 (+5v_(Input)), Module1.79 (+5v_(Input)), Module1.81 (+5v_(Input)), Module1.83 (+5v_(Input)), Module1.85 (+5v_(Input)), Module1.87 (+5v_(Input)); also elsewhere on the board
/CC1: Module1.94 (CC1); also elsewhere on the board
/CC2: Module1.96 (CC2); also elsewhere on the board
/CM5_GPIO ( Ethernet, GPIO, SDCARD)/+1.8v: Module1.88 (+1.8v_(Output)), Module1.90 (+1.8v_(Output)), R4.1
/CM5_GPIO ( Ethernet, GPIO, SDCARD)/BT_nDis: J3.3, Module1.91 (BT_nDisable)
/CM5_GPIO ( Ethernet, GPIO, SDCARD)/CAM_GPIO0: Module1.97 (CAM_GPIO0); also elsewhere on the board
/CM5_GPIO ( Ethernet, GPIO, SDCARD)/CAM_GPIO1: Module1.100 (CAM_GPIO1); also elsewhere on the board
/CM5_GPIO ( Ethernet, GPIO, SDCARD)/EEPROM_nWP: J2.4, Module1.20 (EEPROM_nWP)
/CM5_GPIO ( Ethernet, GPIO, SDCARD)/ETH_LEDG: Module1.17 (Ethernet_nLED2(3.3v)), R2.2
/CM5_GPIO ( Ethernet, GPIO, SDCARD)/ETH_LEDY: Module1.15 (Ethernet_nLED3(3.3v)), R3.2
/CM5_GPIO ( Ethernet, GPIO, SDCARD)/GPIO2: J8.3, Module1.58 (GPIO2)
/CM5_GPIO ( Ethernet, GPIO, SDCARD)/GPIO3: J8.5, Module1.56 (GPIO3)
/CM5_GPIO ( Ethernet, GPIO, SDCARD)/GPIO4: J8.7, Module1.54 (GPIO4)
/CM5_GPIO ( Ethernet, GPIO, SDCARD)/GPIO5: J8.29, Module1.34 (GPIO5)
/CM5_GPIO ( Ethernet, GPIO, SDCARD)/GPIO6: J8.31, Module1.30 (GPIO6)
/CM5_GPIO ( Ethernet, GPIO, SDCARD)/GPIO7: J8.26, Module1.37 (GPIO7)
/CM5_GPIO ( Ethernet, GPIO, SDCARD)/GPIO8: J8.24, Module1.39 (GPIO8)
/CM5_GPIO ( Ethernet, GPIO, SDCARD)/GPIO9: J8.21, Module1.40 (GPIO9)
/CM5_GPIO ( Ethernet, GPIO, SDCARD)/GPIO10: J8.19, Module1.44 (GPIO10)
/CM5_GPIO ( Ethernet, GPIO, SDCARD)/GPIO11: J8.23, Module1.38 (GPIO11)
/CM5_GPIO ( Ethernet, GPIO, SDCARD)/GPIO12: J8.32, Module1.31 (GPIO12)
/CM5_GPIO ( Ethernet, GPIO, SDCARD)/GPIO13: J8.33, Module1.28 (GPIO13)
/CM5_GPIO ( Ethernet, GPIO, SDCARD)/GPIO14: J8.8, Module1.55 (GPIO14)
/CM5_GPIO ( Ethernet, GPIO, SDCARD)/GPIO15: J8.10, Module1.51 (GPIO15)
/CM5_GPIO ( Ethernet, GPIO, SDCARD)/GPIO16: J8.36, Module1.29 (GPIO16)
/CM5_GPIO ( Ethernet, GPIO, SDCARD)/GPIO17: J8.11, Module1.50 (GPIO17)
/CM5_GPIO ( Ethernet, GPIO, SDCARD)/GPIO18: J8.12, Module1.49 (GPIO18)
/CM5_GPIO ( Ethernet, GPIO, SDCARD)/GPIO19: J8.35, Module1.26 (GPIO19)
/CM5_GPIO ( Ethernet, GPIO, SDCARD)/GPIO20: J8.38, Module1.27 (GPIO20)
/CM5_GPIO ( Ethernet, GPIO, SDCARD)/GPIO21: J8.40, Module1.25 (GPIO21)
/CM5_GPIO ( Ethernet, GPIO, SDCARD)/GPIO22: J8.15, Module1.46 (GPIO22)
/CM5_GPIO ( Ethernet, GPIO, SDCARD)/GPIO23: J8.16, Module1.47 (GPIO23)
/CM5_GPIO ( Ethernet, GPIO, SDCARD)/GPIO24: J8.18, Module1.45 (GPIO24)
/CM5_GPIO ( Ethernet, GPIO, SDCARD)/GPIO25: J8.22, Module1.41 (GPIO25)
/CM5_GPIO ( Ethernet, GPIO, SDCARD)/GPIO26: J8.37, Module1.24 (GPIO26)
/CM5_GPIO ( Ethernet, GPIO, SDCARD)/GPIO27: J8.13, Module1.48 (GPIO27)
/CM5_GPIO ( Ethernet, GPIO, SDCARD)/GPIO_VREF: Module1.78 (GPIO_VREF(1.8v/3.3v_Input)), R4.2, R5.2; also elsewhere on the board
/CM5_GPIO ( Ethernet, GPIO, SDCARD)/ID_SC: J8.28, Module1.35 (ID_SC); also elsewhere on the board
/CM5_GPIO ( Ethernet, GPIO, SDCARD)/ID_SD: J8.27, Module1.36 (ID_SD); also elsewhere on the board
/CM5_GPIO ( Ethernet, GPIO, SDCARD)/PMIC_ENABLE: J2.12, Module1.99 (PMIC_ENABLE)
/CM5_GPIO ( Ethernet, GPIO, SDCARD)/PWM: J14.2, Module1.19 (FAN_PWM), R11.2, TP2.1
/CM5_GPIO ( Ethernet, GPIO, SDCARD)/PWR_BUT: J2.14, Module1.92 (PWR_BUT), SW1.1
/CM5_GPIO ( Ethernet, GPIO, SDCARD)/SD_CLK: J7.5 (CLK), Module1.57 (SD_CLK)
/CM5_GPIO ( Ethernet, GPIO, SDCARD)/SD_CMD: J7.3 (CMD), Module1.62 (SD_CMD)
/CM5_GPIO ( Ethernet, GPIO, SDCARD)/SD_DAT0: J7.7 (DAT0), Module1.63 (SD_DAT0)
/CM5_GPIO ( Ethernet, GPIO, SDCARD)/SD_DAT1: J7.8 (DAT1), Module1.67 (SD_DAT1)
/CM5_GPIO ( Ethernet, GPIO, SDCARD)/SD_DAT2: J7.1 (DAT2), Module1.69 (SD_DAT2)
/CM5_GPIO ( Ethernet, GPIO, SDCARD)/SD_DAT3: J7.2 (DAT3/CD), Module1.61 (SD_DAT3)
/CM5_GPIO ( Ethernet, GPIO, SDCARD)/SD_PWR: C5.1, J7.4 (VDD), U18.1 (OUT)
/CM5_GPIO ( Ethernet, GPIO, SDCARD)/SD_PWR_ON: Module1.75 (SD_PWR_ON), R13.2, U18.4 (EN)
/CM5_GPIO ( Ethernet, GPIO, SDCARD)/SYNC_OUT: J2.6, Module1.18 (Ethernet_SYNC_OUT(3.3v))
/CM5_GPIO ( Ethernet, GPIO, SDCARD)/TACHO: J14.4, Module1.16 (FAN_TACHO), TP4.1
/CM5_GPIO ( Ethernet, GPIO, SDCARD)/TR0_TAP: J9.3, U3.11 (VC1)
/CM5_GPIO ( Ethernet, GPIO, SDCARD)/TR1_TAP: J9.1, U3.12 (VC2)
/CM5_GPIO ( Ethernet, GPIO, SDCARD)/TR2_TAP: J9.2, U3.13 (VC3)
/CM5_GPIO ( Ethernet, GPIO, SDCARD)/TR3_TAP: J9.4, U3.14 (VC4)
/CM5_GPIO ( Ethernet, GPIO, SDCARD)/TRD0_N: Module1.10 (Ethernet_Pair0_N), U2.4 (D2+), U2.7, U3.2 (TRD0-)
/CM5_GPIO ( Ethernet, GPIO, SDCARD)/TRD0_P: Module1.12 (Ethernet_Pair0_P), U2.5 (D2-), U2.6, U3.1 (TRD0+)
/CM5_GPIO ( Ethernet, GPIO, SDCARD)/TRD1_N: Module1.6 (Ethernet_Pair1_N), U2.2 (D1-), U2.9, U3.6 (TRD1-)
/CM5_GPIO ( Ethernet, GPIO, SDCARD)/TRD1_P: Module1.4 (Ethernet_Pair1_P), U2.1 (D1+), U2.10, U3.3 (TRD1+)
/CM5_GPIO ( Ethernet, GPIO, SDCARD)/TRD2_N: Module1.9 (Ethernet_Pair2_N), U1.4 (D2+), U1.7, U3.8 (TRD2-)
/CM5_GPIO ( Ethernet, GPIO, SDCARD)/TRD2_P: Module1.11 (Ethernet_Pair2_P), U1.5 (D2-), U1.6, U3.7 (TRD2+)
/CM5_GPIO ( Ethernet, GPIO, SDCARD)/TRD3_N: Module1.5 (Ethernet_Pair3_N), U1.2 (D1-), U1.9, U3.10 (TRD3-)
/CM5_GPIO ( Ethernet, GPIO, SDCARD)/TRD3_P: Module1.3 (Ethernet_Pair3_P), U1.1 (D1+), U1.10, U3.9 (TRD3+)
/CM5_GPIO ( Ethernet, GPIO, SDCARD)/USBOTG: J2.10; also elsewhere on the board
/CM5_GPIO ( Ethernet, GPIO, SDCARD)/VBAT: BT1.1 (+), Module1.76 (VBAT)
/CM5_GPIO ( Ethernet, GPIO, SDCARD)/WL_nDis: J3.1, Module1.89 (WiFi_nDisable)
/CM5_GPIO ( Ethernet, GPIO, SDCARD)/nPWR_LED: Module1.95 (LED_nPWR), R10.2
/CM5_GPIO ( Ethernet, GPIO, SDCARD)/nRPIBOOT: J2.2, Module1.93 (nRPIBOOT)
/CM5_HighSpeed/SCL0: Module1.80 (SCL0); also elsewhere on the board
/CM5_HighSpeed/SDA0: Module1.82 (SDA0); also elsewhere on the board
GND: BT1.2 (-), C1.2, C5.2, J2.1, J2.3, J2.5, J2.7, J2.9, J2.11, J2.13, J3.2, J7.6 (VSS), J7.11 (SHIELD), J8.6, J8.9, J8.14, J8.20, J8.25, J8.30, J8.34, J8.39, J14.3, Module1.1 (GND), Module1.2 (GND), Module1.7 (GND), Module1.8 (GND), Module1.13 (GND), Module1.14 (GND), Module1.22 (GND), Module1.23 (GND), Module1.32 (GND), Module1.33 (GND), Module1.42 (GND), Module1.43 (GND), Module1.52 (GND), Module1.53 (GND), Module1.59 (GND), Module1.60 (GND), Module1.65 (GND), Module1.66 (GND), Module1.71 (GND), Module1.74 (GND), Module1.98 (GND), SW1.2, U1.3 (GND), U1.8 (GND), U2.3 (GND), U2.8 (GND), U3.19 (SHIELD), U3.20 (SHIELD), U18.2 (GND); also elsewhere on the board
unnamed: C1.1, U3.4 (CT), U3.5 (CT)
unnamed: D1.1 (K), R10.1, TP5.1
unnamed: D2.1 (K), R1.1, TP3.1
unnamed: Module1.21 (LED_nACT), R1.2
unnamed: R3.1, U3.18 (LEDG_K)
unnamed: R2.1, U3.16 (LEDY_K)

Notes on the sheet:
40Way GPIO Header
Activity LED
R2 : Simplify nPWR_LED Drive
FAN connector
R2 : Add R13 to support CM4Lite
Ethernet POE Protection
GPIO Voltage select
R2 : Pullup added for Fans that don't have a strong internal pullup
Not Fitted header
POE Header
Force RPIBOOT = Jumper Pins 1-2
PWR LED
Ethernet
CM5Lite SDCARD I/F


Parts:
C2, C7, C8: 10u; C_0805_2012Metric; Part Description 10uF 10% 10V Ceramic Capacitor X7R 0805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
C3: 100uF; CP_EIA-7343-31_Kemet-D; Part Description Capacitor, SP-Cap, 100u, 6.3V, 15mR ESR
C12, C13: 100n; C_0402_1005Metric; Part Description 0.1uF 10% 16V Ceramic Capacitor X7R 040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
J5, J16: Conn_01x22_Female; Hirose_FH12-22S-0.5SH_1x22-1MP_P0.50mm_Horizontal; Part Description 22 Position FFC, FPC Connector Contacts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
J6: THD-02-R; PinHeader_2x02_P2.54mm_Vertical; Part Description PinHeader_2x02_P2.54mm_Vertical
J10, J22: 690-019-298-412; EDAC 690-019-298-412; Part Description HDMI Connector, Right Angle, 19 Contact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
J12: USB3_A; MTCONN_UBAF30-D2011; Part Description Dual USB 3 connector
Module1: ComputeModule5-CM5; Raspberry-Pi-5-Compute-Module; Part Description 100 Position Connector Receptacle, Cent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
R6, R7, R8: 2.2K 1%; R_0402_1005Metric; Part Description Resistor 2.2K M1005 1% 63mW
R12: 15K 1%; R_0402_1005Metric; Part Description Resistor 15K M1005 1% 63mW
U6: AP22653W6; SOT-23-6; Part Description Power Switch/Driver 1:1 P-Channel 2.1A 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
U12: RT9742SNGV; TSOT-23_HandSoldering; Part Description Power Switch/Driver 1:1 N-Channel 500mA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

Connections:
/+3.3v: J5.22, J16.22, R8.1; also elsewhere on the board
/+5v: C2.1, C12.1, U6.1 (IN), U12.1 (IN); also elsewhere on the board
/CM5_GPIO ( Ethernet, GPIO, SDCARD)/CAM_GPIO0: J5.17; also elsewhere on the board
/CM5_GPIO ( Ethernet, GPIO, SDCARD)/CAM_GPIO1: J5.18; also elsewhere on the board
/CM5_GPIO ( Ethernet, GPIO, SDCARD)/GPIO_VREF: R6.1, R7.1; also elsewhere on the board
/CM5_GPIO ( Ethernet, GPIO, SDCARD)/ID_SC: J6.1; also elsewhere on the board
/CM5_GPIO ( Ethernet, GPIO, SDCARD)/ID_SD: J6.3; also elsewhere on the board
/CM5_GPIO ( Ethernet, GPIO, SDCARD)/USBOTG: Module1.101 (USB_OTG_ID); also elsewhere on the board
/CM5_HighSpeed/DPHY0_C_N: J5.8, Module1.127 (MIPI0_C_N)
/CM5_HighSpeed/DPHY0_C_P: J5.9, Module1.129 (MIPI0_C_P)
/CM5_HighSpeed/DPHY0_D0_N: J5.2, Module1.115 (MIPI0_D0_N)
/CM5_HighSpeed/DPHY0_D0_P: J5.3, Module1.117 (MIPI0_D0_P)
/CM5_HighSpeed/DPHY0_D1_N: J5.5, Module1.121 (MIPI0_D1_N)
/CM5_HighSpeed/DPHY0_D1_P: J5.6, Module1.123 (MIPI0_D1_P)
/CM5_HighSpeed/DPHY0_D2_N: J5.11, Module1.133 (MIPI0_D2_N)
/CM5_HighSpeed/DPHY0_D2_P: J5.12, Module1.135 (MIPI0_D2_P)
/CM5_HighSpeed/DPHY0_D3_N: J5.14, Module1.139 (MIPI0_D3_N)
/CM5_HighSpeed/DPHY0_D3_P: J5.15, Module1.141 (MIPI0_D3_P)
/CM5_HighSpeed/DPHY1_C_N: J16.8, Module1.187 (MIPI1_C_N)
/CM5_HighSpeed/DPHY1_C_P: J16.9, Module1.189 (MIPI1_C_P)
/CM5_HighSpeed/DPHY1_D0_N: J16.2, Module1.175 (MIPI1_D0_N)
/CM5_HighSpeed/DPHY1_D0_P: J16.3, Module1.177 (MIPI1_D0_P)
/CM5_HighSpeed/DPHY1_D1_N: J16.5, Module1.181 (MIPI1_D1_N)
/CM5_HighSpeed/DPHY1_D1_P: J16.6, Module1.183 (MIPI1_D1_P)
/CM5_HighSpeed/DPHY1_D2_N: J16.11, Module1.193 (MIPI1_D2_N)
/CM5_HighSpeed/DPHY1_D2_P: J16.12, Module1.195 (MIPI1_D2_P)
/CM5_HighSpeed/DPHY1_D3_N: J16.14, Module1.194 (MIPI1_D3_N)
/CM5_HighSpeed/DPHY1_D3_P: J16.15, Module1.196 (MIPI1_D3_P)
/CM5_HighSpeed/HDMI0_CEC: J22.13 (CEC), Module1.151 (HDMI0_CEC)
/CM5_HighSpeed/HDMI0_CK_N: J22.12 (CK-), Module1.190 (HDMI0_CLK_N)
/CM5_HighSpeed/HDMI0_CK_P: J22.10 (CK+), Module1.188 (HDMI0_CLK_P)
/CM5_HighSpeed/HDMI0_D0_N: J22.9 (D0-), Module1.184 (HDMI0_TX0_N)
/CM5_HighSpeed/HDMI0_D0_P: J22.7 (D0+), Module1.182 (HDMI0_TX0_P)
/CM5_HighSpeed/HDMI0_D1_N: J22.6 (D1-), Module1.178 (HDMI0_TX1_N)
/CM5_HighSpeed/HDMI0_D1_P: J22.4 (D1+), Module1.176 (HDMI0_TX1_P)
/CM5_HighSpeed/HDMI0_D2_N: J22.3 (D2-), Module1.172 (HDMI0_TX2_N)
/CM5_HighSpeed/HDMI0_D2_P: J22.1 (D2+), Module1.170 (HDMI0_TX2_P)
/CM5_HighSpeed/HDMI0_HOTPLUG: J22.19 (HPD/HEAC-), Module1.153 (HDMI0_HOTPLUG)
/CM5_HighSpeed/HDMI0_SCL: J22.15 (SCL), Module1.200 (HDMI0_SCL)
/CM5_HighSpeed/HDMI0_SDA: J22.16 (SDA), Module1.199 (HDMI0_SDA)
/CM5_HighSpeed/HDMI1_CEC: J10.13 (CEC), Module1.149 (HDMI1_CEC)
/CM5_HighSpeed/HDMI1_CK_N: J10.12 (CK-), Module1.166 (HDMI1_CLK_N)
/CM5_HighSpeed/HDMI1_CK_P: J10.10 (CK+), Module1.164 (HDMI1_CLK_P)
/CM5_HighSpeed/HDMI1_D0_N: J10.9 (D0-), Module1.160 (HDMI1_TX0_N)
/CM5_HighSpeed/HDMI1_D0_P: J10.7 (D0+), Module1.158 (HDMI1_TX0_P)
/CM5_HighSpeed/HDMI1_D1_N: J10.6 (D1-), Module1.154 (HDMI1_TX1_N)
/CM5_HighSpeed/HDMI1_D1_P: J10.4 (D1+), Module1.152 (HDMI1_TX1_P)
/CM5_HighSpeed/HDMI1_D2_N: J10.3 (D2-), Module1.148 (HDMI1_TX2_N)
/CM5_HighSpeed/HDMI1_D2_P: J10.1 (D2+), Module1.146 (HDMI1_TX2_P)
/CM5_HighSpeed/HDMI1_HOTPLUG: J10.19 (HPD/HEAC-), Module1.143 (HDMI1_HOTPLUG)
/CM5_HighSpeed/HDMI1_SCL: J10.15 (SCL), Module1.147 (HDMI1_SCL)
/CM5_HighSpeed/HDMI1_SDA: J10.16 (SDA), Module1.145 (HDMI1_SDA)
/CM5_HighSpeed/HDMI_5v: C13.1, J10.18 (+5V), J22.18 (+5V), U12.2 (OUT)
/CM5_HighSpeed/PCIE_CLK_N: Module1.112 (PCIe_CLK_N); also elsewhere on the board
/CM5_HighSpeed/PCIE_CLK_P: Module1.110 (PCIe_CLK_P); also elsewhere on the board
/CM5_HighSpeed/PCIE_PWR_EN: Module1.106 (PCIE_PWR_EN); also elsewhere on the board
/CM5_HighSpeed/PCIE_RX_N: Module1.118 (PCIe_RX_N); also elsewhere on the board
/CM5_HighSpeed/PCIE_RX_P: Module1.116 (PCIe_RX_P); also elsewhere on the board
/CM5_HighSpeed/PCIE_TX_N: Module1.124 (PCIe_TX_N); also elsewhere on the board
/CM5_HighSpeed/PCIE_TX_P: Module1.122 (PCIe_TX_P); also elsewhere on the board
/CM5_HighSpeed/PCIE_nCLKREQ: Module1.102 (PCIe_nCLKREQ); also elsewhere on the board
/CM5_HighSpeed/PCIE_nRST: Module1.109 (PCIe_nRST); also elsewhere on the board
/CM5_HighSpeed/PCIE_nWAKE: Module1.104 (PCIE_nWAKE); also elsewhere on the board
/CM5_HighSpeed/SCL0: J5.20; also elsewhere on the board
/CM5_HighSpeed/SCL1: J6.2, J16.20, R7.2
/CM5_HighSpeed/SDA0: J5.21; also elsewhere on the board
/CM5_HighSpeed/SDA1: J6.4, J16.21, R6.2
/CM5_HighSpeed/USB3-0-D_N: J12.A2 (D-), Module1.136 (USB3-0-D_N)
/CM5_HighSpeed/USB3-0-D_P: J12.A3 (D+), Module1.134 (USB3-0-D_P)
/CM5_HighSpeed/USB3-0-RX_N: J12.A6 (SSRX+), Module1.128 (USB3-0-RX_N)
/CM5_HighSpeed/USB3-0-RX_P: J12.A5 (SSRX-), Module1.130 (USB3-0-RX_P)
/CM5_HighSpeed/USB3-0-TX_N: J12.A9 (SSTX+), Module1.140 (USB3-0-TX_N)
/CM5_HighSpeed/USB3-0-TX_P: J12.A8 (SSTX-), Module1.142 (USB3-0-TX_P)
/CM5_HighSpeed/USB3-1-D_N: J12.B2 (D-), Module1.165 (USB3-1-D_N)
/CM5_HighSpeed/USB3-1-D_P: J12.B3 (D+), Module1.163 (USB3-1-D_P)
/CM5_HighSpeed/USB3-1-RX_N: J12.B6 (SSRX+), Module1.157 (USB3-1-RX_N)
/CM5_HighSpeed/USB3-1-RX_P: J12.B5 (SSRX-), Module1.159 (USB3-1-RX_P)
/CM5_HighSpeed/USB3-1-TX_N: J12.B9 (SSTX+), Module1.169 (USB3-1-TX_N)
/CM5_HighSpeed/USB3-1-TX_P: J12.B8 (SSTX-), Module1.171 (USB3-1-TX_P)
/CM5_HighSpeed/VBUS: C3.1, C7.1, C8.1, J12.A1 (VBUS), J12.B1 (VBUS), U6.6 (OUT)
/CM5_HighSpeed/VBUS_EN: Module1.111 (VBUS_EN), U6.3 (EN)
/USB2_N: Module1.103 (USB2_N); also elsewhere on the board
/USB2_P: Module1.105 (USB2_P); also elsewhere on the board
GND: C2.2, C3.2, C7.2, C8.2, C12.2, C13.2, J5.1, J5.4, J5.7, J5.10, J5.13, J5.16, J5.19, J10.2 (D2S), J10.5 (D1S), J10.8 (D0S), J10.11 (CKS), J10.17 (GND), J10.SH1 (SH), J10.SH2 (SH), J10.SH3 (SH), J10.SH4 (SH), J12.10 (SHIELD), J12.A4 (GND), J12.A7 (DRAIN), J12.B4 (GND), J12.B7 (DRAIN), J16.1, J16.4, J16.7, J16.10, J16.13, J16.16, J16.19, J22.2 (D2S), J22.5 (D1S), J22.8 (D0S), J22.11 (CKS), J22.17 (GND), J22.SH1 (SH), J22.SH2 (SH), J22.SH3 (SH), J22.SH4 (SH), Module1.107 (GND), Module1.108 (GND), Module1.113 (GND), Module1.114 (GND), Module1.119 (GND), Module1.120 (GND), Module1.125 (GND), Module1.126 (GND), Module1.131 (GND), Module1.132 (GND), Module1.137 (GND), Module1.138 (GND), Module1.144 (GND), Module1.150 (GND), Module1.155 (GND), Module1.156 (GND), Module1.161 (GND), Module1.162 (GND), Module1.167 (GND), Module1.168 (GND), Module1.173 (GND), Module1.174 (GND), Module1.179 (GND), Module1.180 (GND), Module1.185 (GND), Module1.186 (GND), Module1.191 (GND), Module1.192 (GND), Module1.197 (GND), Module1.198 (GND), R12.2, U6.2 (GND), U12.3 (GND); also elsewhere on the board
unnamed: J16.17, R8.2
unnamed: R12.1, U6.5 (ILIM)

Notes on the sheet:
USB 3 Pairs P/N swapped to help routing
Jumpers to be fitted if DPHY1 is used
Current Limit switch
DSI/CSI Connectors
Stacked USB connectors


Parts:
C4, C6, C14, C15, C16, C17: 10u; C_0805_2012Metric; Part Description 10uF 10% 10V Ceramic Capacitor X7R 0805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
C10, C19: 100n; C_0402_1005Metric; Part Description 0.1uF 10% 16V Ceramic Capacitor X7R 040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
C11: 4.7nF; C_0402_1005Metric; Part Description 4.7nF capacitor 0402
D3: LED Green; LED_0603_1608Metric; Part Description Green 572nm LED Indication - Discrete 2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
J4: Bus_M.2_Socket_M; M.2 M Key socket; Part Description M.2 M Key connector
L1: 2.2uH; L_Bourns_SRP5030CC; Part Description Inductor, SMT, 2520, 2u2, IRMS=7A, ISAT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
M1: M.2 Screw; Part Description M.2 Screw
M2, M3, M4, M5: M.2 Solder Nut; Part Description Solder nut for M.2 slot
R14: 100K 1%; R_0402_1005Metric; Part Description Resistor 100K M1005 1% 63mW
R15: 10K 1%; R_0402_1005Metric; Part Description Resistor 10K M1005 1% 63mW
R16: 2.2K 1%; R_0402_1005Metric; Part Description Resistor 2.2K M1005 1% 63mW
R17: 1k; R_0402_1005Metric; Part Description Resistor 1K M1005 1% 63mW
TP1: TestPoint; TestPoint_Pad_2.0x2.0mm; Part Description Test point; not fitted
U7: ASEK-32.768KHZ-L-R-T; Crystal_SMD_3225-4Pin_3.2x2.5mm; Part Description 32KHz Xtal oscilator
U8: AP3441SHE-7B; DFN-8-1EP_2x2mm_P0.5mm_EP1.05x1.75mm; Part Description 3A DC-DC converter

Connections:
/+5v: C4.1, C6.1, C10.1, U8.3 (VIN); also elsewhere on the board
/CM5_HighSpeed/PCIE_CLK_N: J4.53 (REFCLKn); also elsewhere on the board
/CM5_HighSpeed/PCIE_CLK_P: J4.55 (REFCLKp); also elsewhere on the board
/CM5_HighSpeed/PCIE_PWR_EN: R14.1, U8.7 (EN); also elsewhere on the board
/CM5_HighSpeed/PCIE_RX_N: J4.43 (PETp0); also elsewhere on the board
/CM5_HighSpeed/PCIE_RX_P: J4.41 (PETn0); also elsewhere on the board
/CM5_HighSpeed/PCIE_TX_N: J4.49 (PERp0); also elsewhere on the board
/CM5_HighSpeed/PCIE_TX_P: J4.47 (PERn0); also elsewhere on the board
/CM5_HighSpeed/PCIE_nCLKREQ: J4.52 (~CLKREQ); also elsewhere on the board
/CM5_HighSpeed/PCIE_nRST: J4.50 (~PERST); also elsewhere on the board
/CM5_HighSpeed/PCIE_nWAKE: J4.54 (~PEWAKE); also elsewhere on the board
/PCIe-M2/FB: C11.2, R15.2, R16.1, U8.1 (FB)
/PCIe-M2/M2_3v3: C11.1, C14.1, C15.1, C16.1, C17.1, C19.1, D3.2 (A), J4.2 (3.3V), J4.4 (3.3V), J4.12 (3.3V), J4.14 (3.3V), J4.16 (3.3V), J4.18 (3.3V), J4.70 (3.3V), J4.72 (3.3V), J4.74 (3.3V), L1.2, R15.1, U7.1 (EN), U7.4 (VDD)
GND: C4.2, C6.2, C10.2, C14.2, C15.2, C16.2, C17.2, C19.2, J4.1 (GND), J4.3 (GND), J4.9 (GND), J4.15 (GND), J4.21 (GND), J4.27 (GND), J4.33 (GND), J4.39 (GND), J4.45 (GND), J4.51 (GND), J4.57 (GND), J4.71 (GND), J4.73 (GND), J4.75 (GND), J4.M1 (GND2230), J4.M2 (GND2242), J4.M3 (GND2260), J4.M4 (GND2280), J4.S1, J4.S2, R14.2, R16.2, U7.2 (GND), U8.4 (PGND), U8.8 (SGND), U8.9 (PAD); also elsewhere on the board
unnamed: D3.1 (K), R17.1, TP1.1
unnamed: J4.10 (DAS/~DSS/~LED1), R17.2
unnamed: J4.68 (SUSCLK), U7.3 (Out)
unnamed: L1.1, U8.6 (LX)

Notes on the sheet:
Activity LED

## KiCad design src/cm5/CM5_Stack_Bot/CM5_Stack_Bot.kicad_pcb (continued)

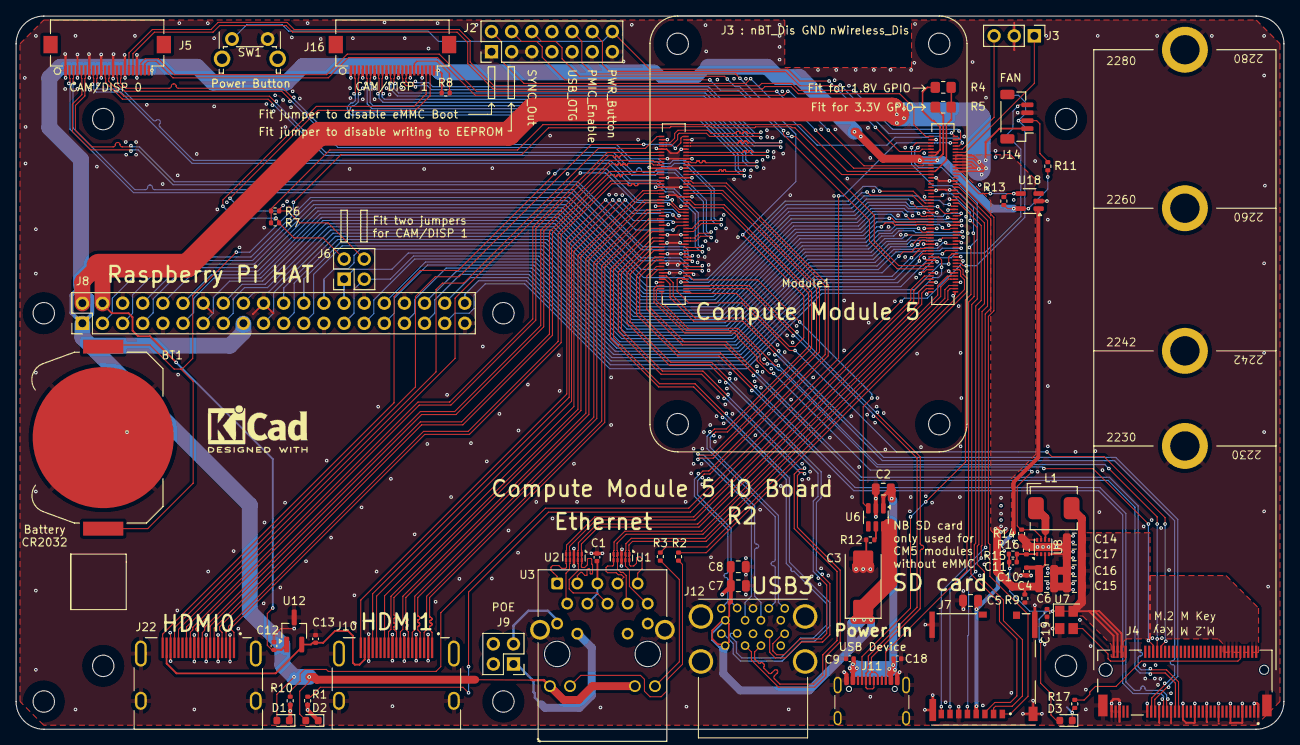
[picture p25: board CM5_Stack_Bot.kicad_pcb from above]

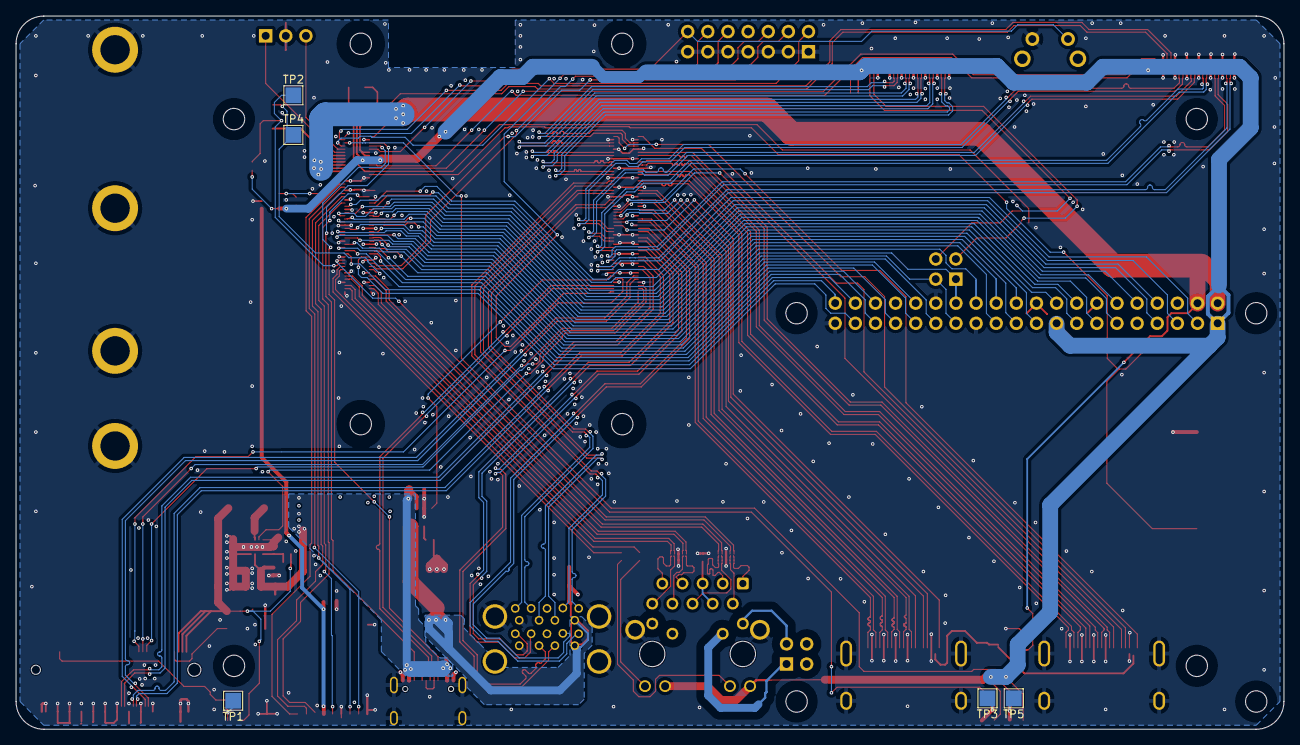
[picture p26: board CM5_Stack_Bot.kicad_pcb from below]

Board: 4 copper layers, 160.0 x 90.0 mm, 78 parts (5 on the bottom side), 160 nets.

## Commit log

2026-06-06 feat(nix): add CM5 gateway NixOS flake and migration assets
    Introduce the gateway-cm5 flake (dual-NIC, NVMe, Essensys stack), OpenSpec
    proposals, agent prompts, KiCad CM5 IO sources, and install documentation.
    [CM5IO.kicad_pcb, CM5IO.kicad_sch, CM5_GPIO.kicad_sch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]
2026-06-06 docs: add CM5 gateway hardware README
    Document the modular 3-board stack architecture, specs, and repository layout.
2026-06-15 docs: site MkDocs gateway CM5 (miroir raspberry-install)
    Structure docs complète, portail remote, cloud-sync, workflow mike pour gh-pages.
2026-06-15 docs: consolidation cloud backend OVH, OpenSpec et checklist E2E.
    Documente le hub unifié essensys-cloud-backend, les phases OpenSpec 0–7 et la validation post-cutover pour mon.essensys.fr.
2026-06-16 chore(openspec): marquer les tâches emails transactionnels comme faites

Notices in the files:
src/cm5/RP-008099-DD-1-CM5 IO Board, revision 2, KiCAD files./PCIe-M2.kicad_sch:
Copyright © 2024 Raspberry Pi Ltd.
